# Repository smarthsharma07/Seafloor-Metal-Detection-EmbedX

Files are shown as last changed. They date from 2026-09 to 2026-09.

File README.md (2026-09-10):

# EmbedX - Seafloor Metal Detection & Target Prioritization

SIH 2026 prototype for a low-cost, deployable ocean-bottom sensor package and desktop analysis dashboard for identifying and localizing possible geophysical anomalies.

## Project Information

- **Project Title:** Low-Cost Deployable Seafloor Metal Detection Sensor for Ocean Resource Exploration
- **PS ID:** 26064
- **PS Title:** Ministry of Earth Sciences / NCPOR seafloor metal-detection and ocean resource exploration problem
- **Category:** Hardware
- **Theme:** Robotics and Drones
- **Prototype Status:** Bench bring-up and simulation verified; hardware validation remains deployment-dependent

## Problem Statement

Ocean resource exploration requires a practical way to collect and inspect multi-sensor measurements from a deployable seafloor package. A prototype must account for sensor validity, pulse-induction and magnetic responses, temperature, motion, recovery logging, and deployment drift without presenting an uncertain location as an exact target or claiming that an anomaly is a confirmed mineral deposit.

## Proposed Solution

The system combines an ESP32-based underwater sensor package with a local FastAPI desktop dashboard. The package collects pulse-induction, magnetic, temperature, inertial, and time data, stores raw telemetry locally, and exposes recovery Wi-Fi/serial access. The dashboard accepts CSV/JSON telemetry, validates and preserves the raw input, calculates conservative anomaly evidence, estimates drift uncertainty, generates IDW interpolated intensity maps, and exports results for review.

This is a decision-support prototype. It does not confirm ore, confirm a mineral, or replace geological and geophysical validation.

## Key Features

- ESP32 firmware with modular sensor drivers for MPU6050, RM3100, MAX31865/PT100, and DS3231.
- Pulse-induction waveform sampling with baseline, decay, noise, and anomaly-strength features.
- Sensor validity flags and diagnostics for each acquisition path.
- DEMO_MODE synthetic telemetry for an end-to-end demonstration without physical hardware.
- Local LittleFS CSV logging and recovery Wi-Fi/serial endpoints.
- FastAPI dashboard for CSV/JSON upload, validation, processing, mapping, and export.
- Configurable **Evidence / Confidence Score** using a rule-based heuristic. **Rule-based, not statistically calibrated.**
- Conservative result labels: `POSSIBLE_METALLIC_ANOMALY`, `POSSIBLE_THERMAL_ANOMALY`, `POSSIBLE_HYDROTHERMAL_ASSOCIATED_ANOMALY`, `MULTISENSOR_ANOMALY`, and `INSUFFICIENT_DATA`.
- IDW interpolation for the prototype heatmap, labelled **Interpolated anomaly intensity** and never treated as a direct measurement.
- Distinct map layers for deployment points, measured anomaly points, interpolated heatmap, drift uncertainty sectors, and candidate overlap regions.
- Candidate scoring based on station evidence scores, spatial overlap, and data quality. No probability-combination formula is used.
- Explicit provenance metadata on results: `MEASURED`, `CALCULATED`, `INFERRED`, or `DEMO`.
- GeoJSON and raw/processed export bundles for reproducible review.

## Scientific and Reporting Guardrails

- The evidence score is a configurable heuristic, not a calibrated probability or statistical certainty.
- The 400 m value is a deployment drift scale / uncertainty extent, not an exact target position.
- Interpolated heatmap cells are calculated estimates between measured points, not direct measurements.
- Raw telemetry is retained separately and is never overwritten by processed data.
- The system reports possible anomalies only. It never outputs `confirmed ore` or `confirmed mineral`.
- Synthetic demonstration records are explicitly tagged `DEMO`.

## Technology Stack

### Embedded package

- PlatformIO
- C++ with the Arduino ESP32 framework
- ESP32 WROOM-32E / ESP32-compatible development board
- I2C, SPI, ADC, GPIO, LittleFS, serial CLI, and recovery Wi-Fi

### Desktop software

- Python 3.10+
- FastAPI and Uvicorn
- HTML, CSS, and vanilla JavaScript frontend
- NumPy, pandas, SciPy, Shapely, and PyProj
- GeoJSON export for GIS-compatible review

## Architecture

```text
                         Surface operator
                                |
                                v
                    FastAPI desktop dashboard
              upload -> validate -> process -> export
                                |
       +------------------------+------------------------+
       |                         |                        |
       v                         v                        v
  Raw telemetry          Heuristic evidence         Map/layer outputs
  preserved              and candidate score       IDW + drift sectors
       ^                         ^                        ^
       |                         |                        |
  ESP32 recovery Wi-Fi    Sensor validity         GeoJSON/report bundle
       ^
       |
  Seafloor sensor package
  PI coil | RM3100 | PT100 | MPU6050 | DS3231
```

Detailed firmware architecture is documented in [docs/ARCHITECTURE.md](docs/ARCHITECTURE.md). The desktop implementation is organized under `desktop_software/backend/` by ingestion, preprocessing, feature extraction, detection, classification, localization, mapping, and reporting responsibilities.

## Repository Structure

```text
Seafloor-Metal-Detection-EmbedX/
├── README.md
├── platformio.ini
├── src/                              # ESP32 firmware
│   ├── main.cpp
│   ├── config.h
│   ├── sensors/                      # MPU6050, RM3100, PT100, DS3231
│   ├── pi/                           # Pulse-induction detector
│   ├── fusion/                       # Attitude, heading, drift fusion
│   ├── logging/                      # Local telemetry logging
│   ├── communication/                # Recovery Wi-Fi and HTTP endpoints
│   └── diagnostics/                  # Hardware self-tests
├── desktop_software/                 # FastAPI analysis dashboard
│   ├── main.py
│   ├── run_dashboard.bat
│   ├── backend/
│   │   ├── ingestion/ preprocessing/ features/
│   │   ├── detection/ classification/ localization/
│   │   ├── mapping/ reports/ models/ demo/
│   ├── frontend/                     # Dashboard HTML, CSS, JavaScript
│   └── data/                         # uploads, demo data, exports
├── docs/                             # Engineering and verification documents
├── test/                             # Firmware-oriented mathematical tests
├── assets/
│   ├── screenshots/                  # Dashboard and prototype images
│   ├── circuit_schematics/           # Wiring diagrams and circuit files
│   └── vessel_schematics_cad/        # Vessel/platform CAD and schematics
└── submission/                       # Presentation and demo links
```

## Installation

Clone the repository and install the desktop dependencies:

```powershell
git clone <YOUR_REPOSITORY_URL>
cd MoES_Sensor_Project_Proposal_V2
python -m venv .venv
.\.venv\Scripts\Activate.ps1
python -m pip install -r desktop_software\requirements.txt
```

PlatformIO can build the firmware from the repository root after installing PlatformIO Core or the PlatformIO IDE extension.

## Run the Desktop Prototype

From the repository root on Windows:

```powershell
desktop_software\run_dashboard.bat
```

Then open [http://127.0.0.1:8000/](http://127.0.0.1:8000/) in a browser. The dashboard must be served through this URL; opening `dashboard.html` directly from the filesystem will not load the dashboard JavaScript correctly.

For a direct Python launch:

```powershell
cd desktop_software
$env:PYTHONPATH = (Get-Location).Path
python -m uvicorn main:app --host 127.0.0.1 --port 8000
```

## Firmware Build and Test

```bash
pio run
python test/test_fusion_math.py
python test/test_prototype_corrections.py
```

The firmware must be bench-tested with the actual sensor wiring before field deployment. Hardware assumptions and unresolved items are recorded in [docs/ASSUMPTIONS.md](docs/ASSUMPTIONS.md) and [docs/KNOWN_LIMITATIONS.md](docs/KNOWN_LIMITATIONS.md).

## Future Scope

- Validate the package with controlled tank, coastal, and vessel trials.
- Replace provisional sensor parameters with calibrated field measurements.
- Add authenticated and encrypted recovery communications for operational deployments.
- Add GIS project packaging and richer survey-line planning after the prototype workflow is stable.

## Our Team

| Member | Role & Contribution |
|---|---|
| **Satwik Pavan** | **Team Leader & Circuit Design** : Led the team and designed, built, and prototyped the sensor circuit and hardware integration. |
| **Shahzeb Shahzad** | **CAD & Mechanical Design** : Led the Designing of CAD models and schematics for the payload carrier/lander and sensor payload. |
| **Smarth Sharma** | **Firmware & Software** : Led the firmware and software development, including MCU programming, sensor interfacing, and data-processing components. |
| **Piyush Goyal** | **Pulse Induction Research** : Researched pulse-induction sensing and contributed to PI coil development. |
| **Ayaan Chauhan** | **PI Coil & MCU Programming** : Worked on pulse-induction coil design and MCU programming. |
| **Shreya Jha** | **Ore Research & Presentation** : Researched relevant seafloor ore properties and developed the project presentation. |

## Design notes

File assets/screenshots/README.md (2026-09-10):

# EmbedX Software Screenshots

Screenshots demonstrating the current software prototype.

- `analysis-dashboard-synthetic.png` : Synthetic-data analysis dashboard.
- `gis-anomaly-map.png` : Geographic anomaly and drift visualization.
- `detection-thresholds.png` : Configurable anomaly detection thresholds.

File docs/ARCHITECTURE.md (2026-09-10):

# Complete Software & Firmware Architecture

This document presents the detailed architectural design of the ESP32 deployment firmware.

---

## 1. Modular Layer Diagram

```
+-------------------------------------------------------------------+
|                        APPLICATION LAYER                          |
|   src/main.cpp (State Machine Orchestrator & Serial CLI Console) |
+-------------------------------+-----------------------------------+
                                |
        +-----------------------+-----------------------+
        |                                               |
+-------v-----------------------+       +---------------+-------+
|    COMMUNICATION & LOGGING    |       |    SIGNAL PROCESSING  |
|  - WiFi Manager (HTTP Server) |       |  - Sensor Fusion      |
|  - Storage Logger (LittleFS)  |       |  - Attitude & Heading |
|  - Diagnostics Self-Test      |       |  - PI Signal Engine   |
+-------+-----------------------+       +---------------+-------+
        |                                               |
        +-----------------------+-----------------------+
                                |
+-------------------------------+-----------------------------------+
|                        HARDWARE DRIVERS                           |
|  - MPU6050 Driver (I2C)     - DS3231 Driver (I2C)                 |
|  - RM3100 Driver (SPI)      - MAX31865 Driver (SPI)               |
+-------------------------------+-----------------------------------+
                                |
+-------------------------------+-----------------------------------+
|                  HARDWARE ABSTRACTION LAYER (HAL)                 |
|  - ESP32 Wire (I2C)         - ESP32 SPI (SPISettings per dev)    |
|  - ESP32 ADC1 (GPIO32)      - ESP32 GPIO (GPIO33 Gate Pulse)      |
+-------------------------------------------------------------------+
```

---

## 2. Directory Structure

- `platformio.ini` : Project build configuration file.
- `src/config.h` : Central configuration macros, GPIO pin mappings, and parameter constants.
- `src/sensors/` : Sensor drivers (MPU6050, DS3231, MAX31865, RM3100).
- `src/pi/` : Pulse Induction coil controller and anomaly detector.
- `src/fusion/` : Attitude complementary filter, tilt-compensated heading, drift sector estimator.
- `src/logging/` : Data logger supporting CSV and LittleFS storage.
- `src/communication/` : Post-recovery Wi-Fi Access Point and HTTP server.
- `src/diagnostics/` : System self-test table and hardware health diagnostics.
- `src/main.cpp` : Entry point, non-blocking time-multiplexed loop state machine, CLI command parser.

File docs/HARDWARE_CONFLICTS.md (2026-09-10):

# Hardware Conflicts & Discrepancies Resolution Report

This document records all conflicts, discrepancies, and contradictions identified across project documents and hardware schematics, along with their engineering resolutions.

---

## 1. Discrepancy Matrix

| Discrepancy ID | Item | Source Document A | Source Document B | Engineering Resolution | Status |
| :--- | :--- | :--- | :--- | :--- | :--- |
| **CONFLICT-01** | Magnetometer Part | PDF 1 & PDF 2 (MMC5983MA / QMC5883L) | PDF 3 & Prompt (RM3100) | Standardized on **RM3100** via SPI bus. QMC5883L/MMC5983MA code excluded. | **RESOLVED** |
| **CONFLICT-02** | I2C Address Collision | MPU6050 schematic (R6=4.7k to GND -> `0x68`) | DS3231 RTC datasheet (Fixed `0x68`) | MPU6050 `AD0` pin **must** be tied to 3.3V (`0x69`). Dynamic probe implemented. | **RESOLVED IN FIRMWARE** |
| **CONFLICT-03** | I2C SCL Pin Mapping | Project prompt text (`I2C SCL -> GPIO?`) | Olimex ESP32-POE EXT2 header (Pin 4 = `GPIO16`) | Set default `I2C_SCL_PIN` to `GPIO16` in `config.h`. Configurable via macro. | **HARDWARE_TBD** |
| **CONFLICT-04** | SPI Clock Mode Conflict | MAX31865 datasheet (Mode 1 / Mode 3, CPHA=1) | RM3100 datasheet (Mode 0, CPOL=0, CPHA=0) | Implemented per-device `SPISettings` before asserting Chip Select. | **RESOLVED IN FIRMWARE** |
| **CONFLICT-05** | MAX31865 $R_{ref}$ Value | Generic MAX31865 docs ($400.0\,\Omega$) | 7Semi Breakout PCB image (Page 1) | Set provisional default $R_{ref} = 430.0\,\Omega$. Marked `UNVERIFIED`. | **HARDWARE_TBD** |

---

## 2. Detailed Technical Evidence & Direct Quotes

### Conflict 01: Magnetometer Sensor Type
- **PDF 1 (Vessel Movement-Direction Prediction, Page 1):**
  > "Three Sources of Direction Information: MMC5983MA magnetometer - Measures the Earth's magnetic-field vector..."
- **PDF 2 (Project Proposal & Concept Note, Page 4):**
  > "Magnetometer: QMC5883L (Unconfirmed)"
- **PDF 3 (Sensor Schematics, Page 3):**
  > "Magnetometer – RM3100: SPI interface (SCK, SO, SI, SSN, DRDY, I2CEN=GND)"
- **User Request Instructions:**
  > "The latest hardware design uses RM3100. Do NOT implement QMC5883L support unless explicitly requested later."
- **Resolution:** `RM3100` driver implemented via SPI.

### Conflict 02: I2C Address Collision between MPU6050 and DS3231
- **PDF 3 (MPU6050 Schematic, Page 2):**
  > Circuit schematic shows resistor `R6 (4.7K)` pulling `AD0` pin to `GND`. When `AD0` is LOW, MPU6050 I2C 7-bit slave address is `0x68`.
- **DS3231 Datasheet Standard:**
  > Fixed 7-bit slave address `0x68`.
- **Engineering Risk:** If both chips share address `0x68` on the same I2C bus, bus contention occurs and both devices fail to read.
- **Resolution:**
  1. Hardware requirement: Tie MPU6050 `AD0` externally to `3.3V` (sets address to `0x69`).
  2. Software safety: `MPU6050` driver tests `0x69` first; if not detected, attempts `0x68` only if DS3231 probe is inactive.

### Conflict 03: I2C SCL Pin Mapping
- **User Prompt:**
  > `I2C: SDA -> GPIO13, SCL -> GPIO?`
- **Olimex ESP32-POE EXT2 Header Analysis:**
  > EXT2 Pin 3 = `GPIO13` (SDA)
  > EXT2 Pin 4 = `GPIO16` (SCL)
- **Resolution:** Set default `I2C_SCL_PIN` to `16` in `src/config.h`, but explicitly document as `HARDWARE_TBD` until physical bench continuity check is confirmed.

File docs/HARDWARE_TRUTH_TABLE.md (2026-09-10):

# Hardware Truth Table & Pre-Flight Review

This document establishes the hardware verification matrix for the deployable ocean-bottom sensor package based on direct inspection of supplied schematics, breakout board pinouts, and project architecture documents.

> [!CAUTION]
> **PRE-FLIGHT HARDWARE STATUS:** All GPIO assignments are currently classified as **PROVISIONAL / BENCH_TBD** pending physical electrical continuity checks and confirmation of the exact PCB revision.

---

## 1. Peripheral Hardware Matrix

| Function | Device | ESP32 GPIO | Physical Header Pin | Bus | Direction | Active Level | Voltage | Source Document | Verification Status | Engineering Notes |
| :--- | :--- | :--- | :--- | :--- | :--- | :--- | :--- | :--- | :--- | :--- |
| **I2C SDA** | MPU6050 / DS3231 | `GPIO13` | EXT2 Pin 3 | I2C | Bidirectional | Open-Drain (4.7k Pull-up) | 3.3V | Project Wiring / EXT2 Map | **PROVISIONAL (BENCH_TBD)** | Shared I2C Data line. |
| **I2C SCL** | MPU6050 / DS3231 | `GPIO16` *(Default)* | EXT2 Pin 4 | I2C | Output | Open-Drain (4.7k Pull-up) | 3.3V | Olimex EXT2 Reference / Prompt `GPIO?` | **UNVERIFIED (BENCH_TBD)** | Prompt states `GPIO?`. EXT2 Pin 4 is GPIO16 on Olimex WROOM. |
| **SPI MISO** | RM3100 / MAX31865 | `GPIO2` | EXT1 Pin 3 | SPI | Input | Logic | 3.3V | Project Wiring / EXT1 Map | **PROVISIONAL (BENCH_TBD)** | Shared Master-In-Slave-Out line. |
| **SPI MOSI** | RM3100 / MAX31865 | `GPIO15` | EXT2 Pin 8 | SPI | Output | Logic | 3.3V | Project Wiring / EXT2 Map | **PROVISIONAL (BENCH_TBD)** | Shared Master-Out-Slave-In line. |
| **SPI SCK** | RM3100 / MAX31865 | `GPIO14` | EXT2 Pin 7 | SPI | Output | Logic | 3.3V | Project Wiring / EXT2 Map | **PROVISIONAL (BENCH_TBD)** | Shared Serial Clock line. |
| **RM3100 CS** | RM3100 Magnetometer | `GPIO4` | EXT1 Pin 4 | SPI CS | Output | Active LOW | 3.3V | Project Wiring / EXT1 Map | **PROVISIONAL (BENCH_TBD)** | Dedicated SPI Chip Select (SSN). SPI Mode 0. |
| **MAX31865 CS** | MAX31865 RTD | `GPIO5` | EXT1 Pin 5 | SPI CS | Output | Active LOW | 3.3V | Project Wiring / EXT1 Map | **PROVISIONAL (BENCH_TBD)** | Dedicated SPI Chip Select. SPI Mode 1. |
| **PI Trigger** | PI MOSFET Gate | `GPIO33` | EXT2 Pin 5 | GPIO | Output | Active HIGH | 3.3V -> Gate | Project Wiring / EXT2 Map | **PROVISIONAL (BENCH_TBD)** | Pulse Induction MOSFET gate pulse. |
| **PI ADC Input** | PI Decay Signal | `GPIO32` | EXT2 Pin 6 | ADC1_CH4 | Analog Input | Analog (0-3.3V) | 0-3.3V | Project Wiring / EXT2 Map | **PROVISIONAL (BENCH_TBD)** | ADC1 Channel 4; unaffected by Wi-Fi operations. |
| **DS3231 Address** | DS3231 RTC | N/A (I2C: `0x68`) | N/A | I2C | N/A | N/A | 3.3V | DS3231 Datasheet | **VERIFIED (I2C Standard)** | Fixed I2C slave address `0x68`. Initialized first in setup. |
| **MPU6050 Address** | MPU6050 IMU | N/A (I2C: `0x69`) | N/A | I2C | N/A | N/A | 3.3V | MPU6050 Schematic (Page 2) | **MANDATORY HARDWARE REQUIREMENT** | Breakout schematic shows R6 4.7k pull-down on AD0 (`0x68`). Must wire AD0 to 3.3V (`0x69`) to avoid bus collision. |
| **RM3100 I2CEN** | RM3100 Magnetometer | N/A (GND) | N/A | Discrete | Input | Active LOW (GND) | 0V | Sensor Schematics (Page 3) | **PROVISIONAL (BENCH_TBD)** | Must be tied to GND to force SPI protocol mode. |
| **MAX31865 $R_{ref}$**| 7Semi Board Resistor | N/A | PCB Surface | Analog | Precision | N/A | N/A | 7Semi Breakout PCB (Page 1) | **UNVERIFIED (BENCH_TBD)** | Default $430.0\,\Omega$. Must measure SMD resistor on physical board. |

---

## 2. Power and Grounding Architecture

- **Main Input:** $5.0\,\text{V}$ DC from step-down buck converter powered by $12\,\text{V}, 5\,\text{Ah}$ Li-Ion battery pack.
- **Sensor Logic Power:** $3.3\,\text{V}$ rail for MPU6050, DS3231, RM3100 (AVDD/DVDD), and MAX31865 (VIN/3V3).
- **Grounding Requirement:** Star-ground topology connecting digital logic ground, analog sensor ground, and MOSFET source return at a single point to prevent high-current PI induction switching transients from corrupting RTD and magnetometer readings.

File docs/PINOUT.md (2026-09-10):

# Hardware Pinout & Wiring Specification

This document provides the verified pinout and physical header wiring mapping for the ESP32 deployment package.

---

## 1. ESP32 Extension Header Pin Assignments

```
               Olimex ESP32-POE / WROOM Extension Headers

         EXT1 (Left Header)                EXT2 (Right Header)
      +----------------------+          +----------------------+
      | 1 : 3.3V Power       |          | 1 : 5.0V Power       |
      | 2 : GND              |          | 2 : GND              |
      | 3 : GPIO2  (MISO)    |          | 3 : GPIO13 (I2C SDA) |
      | 4 : GPIO4  (RM CS)   |          | 4 : GPIO16 (I2C SCL)*|
      | 5 : GPIO5  (MAX CS)  |          | 5 : GPIO33 (PI Gate) |
      | 6 : GPIO18           |          | 6 : GPIO32 (PI ADC)  |
      | ...                  |          | 7 : GPIO14 (SPI SCK) |
      +----------------------+          | 8 : GPIO15 (SPI MOSI)|
                                        +----------------------+
```

*Note: SCL is mapped to EXT2 Pin 4 (`GPIO16`). Default configurable via `I2C_SCL_PIN` in `config.h`.

---

## 2. Bus Allocation Summary

### I2C Bus (`Wire`)
- **SDA:** `GPIO13` (EXT2 Pin 3)
- **SCL:** `GPIO16` (EXT2 Pin 4) - *HARDWARE_TBD*
- **Devices:**
  - `DS3231` RTC (Fixed address `0x68`)
  - `MPU6050` IMU (Address `0x69` when AD0 tied to 3.3V)

### SPI Bus (`SPI`)
- **MOSI:** `GPIO15` (EXT2 Pin 8)
- **MISO:** `GPIO2`  (EXT1 Pin 3)
- **SCK:**  `GPIO14` (EXT2 Pin 7)
- **Devices:**
  - `RM3100` Magnetometer (`CS` = `GPIO4`, SPI Mode 0, 1 MHz max)
  - `MAX31865` RTD Converter (`CS` = `GPIO5`, SPI Mode 1/3, 1 MHz max)

### Discrete Analog / GPIO
- **PI MOSFET Gate Trigger:** `GPIO33` (EXT2 Pin 5) - Digital Output
- **PI Signal Decay ADC Input:** `GPIO32` (EXT2 Pin 6) - `ADC1_CH4`

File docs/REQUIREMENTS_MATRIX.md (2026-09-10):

# Requirements Traceability Matrix

This document maps all SIH project requirements to firmware implementation modules, input/output interfaces, and verification statuses.

---

## 1. Traceability Matrix

| Req ID | Requirement Description | Implementation Module | Primary Input | Primary Output | Verification Method | Status |
| :--- | :--- | :--- | :--- | :--- | :--- | :--- |
| **REQ-DRV-01** | MPU6050 Motion Sensing & Die Temp | `src/sensors/mpu6050.h/cpp` | I2C Bus (`0x69` default) | Accel ($\text{m}/\text{s}^2$), Gyro ($\text{rad}/\text{s}$), Die Temp ($^\circ\text{C}$), `mpu_valid` | Startup Identity Check (`WHO_AM_I=0x68`), Static Code Review | **[SOURCE VERIFIED]** (Pending Bench Test) |
| **REQ-DRV-02** | DS3231 RTC Timestamping | `src/sensors/ds3231.h/cpp` | I2C Bus (`0x68` fixed) | Unix Epoch, ISO-8601 String, `rtc_valid` | Range Sanity Check & Status Probe | **[SOURCE VERIFIED]** (Pending Bench Test) |
| **REQ-DRV-03** | MAX31865 Seawater Temperature | `src/sensors/max31865_pt100.h/cpp` | SPI Bus (`GPIO5` CS, Mode 1) | RTD Ohms, Seawater Temp ($^\circ\text{C}$), `rtd_valid` | Quadratic CVD Math & Config Readback | **[SOURCE VERIFIED]** (Pending Bench Test) |
| **REQ-DRV-04** | RM3100 3-Axis Magnetometer | `src/sensors/rm3100.h/cpp` | SPI Bus (`GPIO4` CS, Mode 0) | Magnetic Vector ($\mu\text{T}$), `mag_valid` | REVID Check (`0x36`) & CC Readback | **[SOURCE VERIFIED]** (Pending Bench Test) |
| **REQ-PI-01** | Parameterized PI Anomaly Detector | `src/pi/pi_detector.h/cpp` | `GPIO33` Gate, `GPIO32` ADC1_CH4 | Raw Decay[16], Baseline, Peak, Early/Late, Strength, `pi_valid` | Multi-burst Acquisition & Sigma Derivation | **[PROVISIONAL]** (Pending Coil Bench Test) |
| **REQ-FUS-01** | IMU Attitude Filter (Roll/Pitch) | `src/fusion/attitude.h/cpp` | Calibrated Accel & Gyro | Roll ($\phi$), Pitch ($\theta$) | Mathematical Simulation | **[SOURCE VERIFIED]** |
| **REQ-FUS-02** | Tilt-Compensated Heading | `src/fusion/heading.h/cpp` | Calibrated Mag + Roll/Pitch | Heading ($\psi$, $0-360^\circ$), Calibrated $\mu\text{T}$ | Synthetic Vector Test (`test_fusion_math.py`) | **[SIMULATION VERIFIED]** |
| **REQ-FUS-03** | Conditional Drift Sector Fusion | `src/fusion/drift_fusion.h/cpp` | Mag Heading + IMU Motion | `accel_horiz_mag`, `imu_direction_valid`, `drift_bearing`, `drift_radius`, `uncertainty_deg` | Synthetic Vector Test (`test_fusion_math.py`) | **[SIMULATION VERIFIED]** |
| **REQ-FUS-04** | Separate Confidence Metrics | `src/fusion/drift_fusion.h/cpp` | Field Magnitude & Motion SNR | `mag_conf`, `imu_conf`, `fusion_conf` | Confidence Metric Analysis | **[SIMULATION VERIFIED]** |
| **REQ-LOG-01** | Telemetry Data Logging | `src/logging/logger.h/cpp` | Unified `SensorSample` | LittleFS CSV File (`/telemetry.csv`) | Storage Schema Review | **[SOURCE VERIFIED]** |
| **REQ-COM-01** | Recovery Wi-Fi Server | `src/communication/wifi_manager.h/cpp` | LittleFS Files | Endpoints: `/`, `/status`, `/config`, `/calibration`, `/files`, `/download` | HTTP Route Handler Review | **[SOURCE VERIFIED]** |
| **REQ-SIM-01** | DEMO_MODE Simulation Engine | `src/main.cpp` | Synthetic Timers | Full Simulated Telemetry Pipeline | End-to-End Simulation Step | **[SOURCE VERIFIED]** |
| **REQ-DIAG-01**| Boot Diagnostics & CLI | `src/diagnostics/diagnostics.h/cpp` & `src/main.cpp` | Sensor Init Status & CLI | Self-Test Table, CLI (`piread`, `pical`, `magcal`, `imucal`, `demo`) | Interactive CLI Review | **[SOURCE VERIFIED]** |

---

## 2. Verification Classification Standard

1. **`[SOURCE VERIFIED]`**: Code structure, driver registers, error handling, and syntax verified via code review and static analysis.
2. **`[SIMULATION VERIFIED]`**: Mathematical algorithms (attitude filter, heading projection, conditional IMU motion, drift fusion) validated against synthetic test vectors (`test/test_fusion_math.py`).
3. **`[PROVISIONAL / BENCH_TBD]`**: Hardware interactions (PI coil decay curves, RTD reference resistor, SCL pin continuity) requiring physical bench testing.
4. **`[BENCH HARDWARE VERIFIED]`**: Validated on physical electronics workbench with actual breakout boards. *(PENDING).*
5. **`[FIELD VERIFIED]`**: Confirmed during open-ocean sea trials and drift deployment experiments. *(PENDING).*

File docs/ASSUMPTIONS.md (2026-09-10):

# Engineering Assumptions Document

This document lists every explicit engineering assumption made during the design and software architecture of the deployable seafloor metal-detection sensor package.

---

## 1. Hardware & Electrical Assumptions

1. **ESP32 Board Mapping:** Assumed Olimex ESP32-POE or compatible ESP32-WROOM-32E module pinout. `I2C_SCL_PIN` defaults to `GPIO16` (EXT2 Pin 4) as a provisional value, marked `UNVERIFIED BENCH_TBD`.
2. **I2C Pull-Up Resistors:** Assumed physical pull-up resistors ($4.7\,\text{k}\Omega$) are present on `SDA` (`GPIO13`) and `SCL` (`GPIO16`).
3. **MPU6050 Address Modification:** Mandatory requirement that MPU6050 `AD0` pin is tied to `3.3V` to force address `0x69`, avoiding hard bus collision with the DS3231 RTC (`0x68`).
4. **MAX31865 Reference Resistor:** Assumed 7Semi MAX31865 module uses a $430.0\,\Omega$ reference resistor ($R_{ref} = 430.0\,\Omega$) for PT100 elements. Marked `UNVERIFIED BENCH_TBD`.
5. **PT100 Configuration:** Assumed 2-wire PT100 RTD with Callendar-Van Dusen equation coefficients ($R_0 = 100.0\,\Omega, A = 3.9083 \times 10^{-3}, B = -5.775 \times 10^{-7}$).
6. **PI Coil Hardware Isolation:** Assumed the Pulse Induction MOSFET driver circuit includes flyback clamping diodes and voltage divider networks to clamp decay signals within the ESP32 `ADC1` range ($0.0\,\text{V} - 3.3\,\text{V}$).

---

## 2. Localization & Sensor Fusion Assumptions

7. **Passive Hydrodynamic Fin Alignment:** Assumed mechanical current-alignment fins passively rotate the cylindrical housing so its longitudinal axis aligns with the local current vector.
8. **No Electronic Fin Sensor:** Assumed there is **no electronic sensor** monitoring fin angle relative to the vessel. The magnetometer reading represents the current-aligned direction directly.
9. **Short-Term IMU Role:** Assumed MPU6050 accelerometer and gyroscope data are used exclusively for tilt compensation and short-term transient motion estimation, **not for long-duration 400 m underwater dead-reckoning**.
10. **Default Drift Scale:** Assumed nominal deployment-to-seafloor drift distance is $400\,\text{m}$ (configurable parameter).

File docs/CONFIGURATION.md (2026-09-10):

# Configuration & Parameters Guide

This document describes all centralized configuration macros, parameter structures, default values, and runtime modification interfaces.

---

## 1. Global Configuration Structure (`src/config.h`)

### Hardware Pin Definitions
```cpp
#define I2C_SDA_PIN         13      // EXT2 Pin 3
#define I2C_SCL_PIN         16      // EXT2 Pin 4 (HARDWARE_TBD)
#define SPI_MOSI_PIN        15      // EXT2 Pin 8
#define SPI_MISO_PIN        2       // EXT1 Pin 3
#define SPI_SCK_PIN         14      // EXT2 Pin 7
#define RM3100_CS_PIN       4       // EXT1 Pin 4
#define MAX31865_CS_PIN     5       // EXT1 Pin 5
#define PI_MOSFET_GATE_PIN  33      // EXT2 Pin 5
#define PI_ADC_INPUT_PIN    32      // EXT2 Pin 6 (ADC1_CH4)
```

### Sensor Settings & Bus Speeds
```cpp
#define I2C_BUS_SPEED       400000U // 400 kHz Fast-mode I2C
#define MPU6050_I2C_ADDR    0x69    // Address with AD0 pulled HIGH
#define DS3231_I2C_ADDR     0x68    // Fixed RTC Address
#define MAX31865_RREF       430.0f  // Reference resistor (UNVERIFIED)
#define MAX31865_RNOMINAL   100.0f  // PT100 Nominal 0C resistance
```

### Pulse Induction Engine Parameters
```cpp
#define PI_PULSE_WIDTH_US   150     // PROVISIONAL
#define PI_SETTLING_DELAY_US 30     // PROVISIONAL
#define PI_PULSE_PERIOD_US  1000    // PROVISIONAL
#define PI_SAMPLE_COUNT     16      // Decay curve samples
#define PI_AVERAGING_COUNT  20      // Pulse averaging
```

---

## 2. Runtime CLI Configuration

All parameters can be queried and modified at runtime via the serial console interface using commands:
- `config` : Prints current parameter list.
- `set pitime <width_us> <settle_us> <period_us>` : Updates PI timing parameters.
- `set dithresh <threshold_counts>` : Updates PI metal anomaly detection threshold.
- `set drift <radius_m> <angle_deg>` : Updates drift radius and sector uncertainty angle.

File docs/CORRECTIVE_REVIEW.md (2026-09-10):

# Engineering Corrective Review & Gap Analysis

This document records the systematic review of the SIH seafloor metal-detection sensor package codebase and documentation, identifying discrepancies, severity levels, root causes, proposed fixes, and hardware verification requirements.

---

## 1. Discrepancy & Defect Register

| ID | Category | Issue Description | Severity | Evidence in Code / Docs | Proposed Engineering Fix | Hardware Verification Required? |
| :--- | :--- | :--- | :--- | :--- | :--- | :--- |
| **CR-01** | Hardware / Pinout | Premature declaration of GPIO pinout as confirmed without physical continuity test. | **HIGH** | `HARDWARE_TRUTH_TABLE.md` listed pins as CONFIRMED based on Olimex reference diagrams. | Reclassify all pins as `PROVISIONAL / BENCH_TBD` until physical continuity and board revision are confirmed. | **YES** |
| **CR-02** | I2C Protocol / Safety | MPU6050 fallback probe to `0x68` creates unsafe bus collision with DS3231 RTC. | **CRITICAL** | `mpu6050.cpp` probed `0x68` if `0x69` failed, potentially driving DS3231. | Initialize DS3231 at `0x68` first. Strictly enforce MPU6050 at `0x69`. Abort with clear error if `0x69` is missing. | **YES** |
| **CR-03** | Data Model | Temperature collision: MPU6050 internal die temperature overwrote PT100 seawater temperature. | **CRITICAL** | `main.cpp` passed `g_latestSample.temperature_C` to `g_mpu.readScaled()`, overwriting PT100 reading. | Separate into `water_temperature_C` (MAX31865 PT100) and `imu_temperature_C` (MPU6050 die temp) in `SensorSample`. | **NO** (Software fix) |
| **CR-04** | Serial CLI | `piread` command only printed stale cached telemetry rather than triggering an active measurement. | **MEDIUM** | `main.cpp` printed `g_latestSample.pi_response_strength` without invoking `g_pi.processPulseSequence()`. | Execute a live PI pulse sequence within `piread` CLI handler and print real-time decay and delta counts. | **YES** (Bench verification) |
| **CR-05** | Calibration CLI | `magcal`, `imucal`, and `pical` routines were documented but lacked implementation in CLI. | **HIGH** | `main.cpp` lacked logic for multi-point mag sampling and stationary gyro offset averaging. | Implement multi-sample interactive calibration loops in `main.cpp` and update `HeadingCalculator` / `AttitudeFilter`. | **YES** (Bench verification) |
| **CR-06** | Web Recovery API | Endpoints `/config` and `/calibration` were documented in help/docs but not bound in `wifi_manager.cpp`. | **MEDIUM** | `wifi_manager.cpp` only had `/`, `/status`, `/files`, `/download`. | Implement dedicated `/config` (JSON) and `/calibration` (JSON) endpoints in `WiFiRecoveryManager`. | **NO** (Software fix) |
| **CR-07** | Logging Claims | Documentation claimed "binary log format" support when only CSV logging is implemented. | **LOW** | `DATA_FORMAT.md` & `ARCHITECTURE.md` mentioned binary format. | Remove all binary logging claims. Explicitly document LittleFS CSV logging as the sole storage format. | **NO** (Doc fix) |
| **CR-08** | RTD Math | Linear Callendar-Van Dusen equation used ($R(T) = R_0(1+AT)$), omitting second-order $B T^2$ term. | **MEDIUM** | `max31865_pt100.cpp` used linear equation while docs claimed full CVD. | Implement quadratic Callendar-Van Dusen formula for $T \ge 0^\circ\text{C}$ and accurately document the calculation. | **NO** (Math fix) |
| **CR-09** | RTD Hardware | $R_{ref} = 430.0\,\Omega$ was hardcoded without measuring the physical 7Semi board resistor. | **HIGH** | `config.h` defined `MAX31865_RREF_OHMS 430.0f`. | Maintain configurable $R_{ref}$ and explicitly mark as `UNVERIFIED / BENCH_TBD`. | **YES** |
| **CR-10** | PI Concurrency | PI pulse sequence claimed to be non-blocking but utilized microsecond delay loops. | **HIGH** | `pi_detector.cpp` used synchronous `delayMicroseconds()` loops. | Clarify that PI pulse bursts require microsecond-level timing and implement non-blocking inter-pulse state scheduling. | **YES** |
| **CR-11** | RM3100 Gain | Fixed 75 LSB/uT gain assumed cycle count of 200 without runtime verification. | **MEDIUM** | `rm3100.cpp` assumed default 200 counts without verifying register write success. | Verify cycle count register readback during `begin()` before applying 75 LSB/uT gain factor. | **YES** |
| **CR-12** | Drift Fusion Claims | Documentation risked implying 400 m dead reckoning. | **HIGH** | Various docs needed clearer distinction between drift sector estimation and dead reckoning. | Emphasize throughout all docs that drift fusion is a statistical uncertainty sector model, NOT dead reckoning. | **NO** (Doc fix) |
| **CR-13** | Traceability | `REQUIREMENTS_MATRIX.md` claimed `[BUILD VERIFIED]` before environment build execution. | **MEDIUM** | Requirements matrix marked statuses optimistically. | Re-evaluate verification statuses honestly against strict build and simulation criteria. | **NO** (Doc fix) |

---

## 2. Corrective Action Plan

1. **Step 1:** Update `src/config.h` with separated temperature fields, unverified markers, and clean calibration structs.
2. **Step 2:** Refactor `src/sensors/mpu6050.cpp` to eliminate `0x68` fallback when DS3231 is active.
3. **Step 3:** Implement quadratic Callendar-Van Dusen equation and register readback verification in `src/sensors/max31865_pt100.cpp`.
4. **Step 4:** Implement cycle count verification in `src/sensors/rm3100.cpp`.
5. **Step 5:** Refactor `src/pi/pi_detector.cpp` with honest timing documentation and non-blocking pulse acquisition cycle.
6. **Step 6:** Implement full interactive `magcal`, `imucal`, and `pical` routines and live `piread` in `src/main.cpp`.
7. **Step 7:** Implement `/config` and `/calibration` endpoints in `src/communication/wifi_manager.cpp`.
8. **Step 8:** Reconcile all 15 documentation files to remove unimplemented features (e.g. binary logging) and accurately describe approximations, calibration workflows, and provisional parameters.

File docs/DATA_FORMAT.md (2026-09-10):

# Data Format Specification

This document details the telemetry logging CSV file format and the JSON schemas served by the Wi-Fi Recovery web server.

---

## 1. Local LittleFS CSV Telemetry Log (`/telemetry.csv`)

Telemetry is written directly to the onboard LittleFS filesystem as a standardized CSV file.

### CSV Header Definition
```csv
timestamp,water_temp_C,imu_temp_C,rtd_ohms,accel_x,accel_y,accel_z,gyro_x,gyro_y,gyro_z,mag_x,mag_y,mag_z,heading,roll,pitch,pi_strength,pi_detected,drift_bearing,confidence
```

### Sample Record
```csv
2026-09-07T14:30:00.000Z,24.15,31.20,109.42,0.02,-0.01,9.81,0.001,-0.002,0.000,21.50,-12.30,42.10,145.20,0.12,-0.06,12.4,0,145.20,0.85
```

### Column Field Descriptions
| Column Index | Field Name | Unit | Type | Description |
| :--- | :--- | :--- | :--- | :--- |
| 1 | `timestamp` | ISO-8601 UTC | String | Formatted UTC timestamp retrieved from DS3231 RTC. |
| 2 | `water_temp_C` | $^\circ\text{C}$ | Float | Seawater temperature measured by MAX31865 PT100 probe. |
| 3 | `imu_temp_C` | $^\circ\text{C}$ | Float | Internal MPU6050 die temperature. |
| 4 | `rtd_ohms` | $\Omega$ | Float | Measured RTD probe resistance. |
| 5-7 | `accel_x, accel_y, accel_z` | $\text{m}/\text{s}^2$ | Float | Calibrated 3-axis acceleration. |
| 8-10 | `gyro_x, gyro_y, gyro_z` | $\text{rad}/\text{s}$ | Float | Calibrated 3-axis angular rates. |
| 11-13 | `mag_x, mag_y, mag_z` | $\mu\text{T}$ | Float | Calibrated 3-axis magnetic field vector. |
| 14 | `heading` | Degrees ($0-360^\circ$) | Float | Tilt-compensated magnetic heading. |
| 15-16 | `roll, pitch` | Degrees | Float | Computed vessel attitude from complementary filter. |
| 17 | `pi_strength` | ADC Counts | Float | Pulse Induction decay anomaly magnitude above baseline. |
| 18 | `pi_detected` | Boolean ($0/1$) | Integer | 1 if `pi_strength` exceeds threshold; 0 otherwise. |
| 19 | `drift_bearing` | Degrees ($0-360^\circ$) | Float | Estimated current-aligned dominant drift bearing. |
| 20 | `confidence` | Scale ($0.0 - 1.0$) | Float | Directional sector fusion confidence score. |

---

## 2. Recovery Wi-Fi JSON API Endpoints

### A. Live Status API (`GET /status`)
```json
{
  "timestamp": "2026-09-07T14:30:00.000Z",
  "water_temperature_C": 24.15,
  "imu_temperature_C": 31.20,
  "rtd_ohms": 109.42,
  "accel": {"x": 0.02, "y": -0.01, "z": 9.81},
  "gyro": {"x": 0.001, "y": -0.002, "z": 0.000},
  "mag_uT": {"x": 21.50, "y": -12.30, "z": 42.10},
  "heading_deg": 145.20,
  "attitude": {"roll_deg": 0.12, "pitch_deg": -0.06},
  "pi_detector": {
    "strength": 12.4,
    "detected": false,
    "baseline": 105.2
  },
  "drift_fusion": {
    "bearing_deg": 145.20,
    "uncertainty_deg": 30.0,
    "radius_m": 400.0,
    "confidence": 0.85
  }
}
```

### B. Configuration API (`GET /config`)
```json
{
  "i2c": {"sda": 13, "scl": 16, "speed": 400000, "mpu_addr": "0x69", "ds3231_addr": "0x68"},
  "spi": {"sck": 14, "miso": 2, "mosi": 15, "rm3100_cs": 4, "max31865_cs": 5},
  "pi": {"gate_gpio": 33, "adc_gpio": 32, "width_us": 150, "settle_us": 30, "period_us": 1000, "threshold": 50.0},
  "fusion": {"w_mag": 0.80, "w_imu": 0.20, "drift_radius_m": 400.0, "uncertainty_deg": 30.0}
}
```

### C. Calibration API (`GET /calibration`)
```json
{
  "mag": {
    "offset": {"x": 2.15, "y": -1.40, "z": 5.80},
    "scale": {"x": 1.02, "y": 0.98, "z": 1.00},
    "calibrated": true
  },
  "imu": {
    "accel_offset": {"x": 0.015, "y": -0.020, "z": 0.005},
    "gyro_offset": {"x": 0.0012, "y": -0.0008, "z": 0.0002},
    "calibrated": true
  }
}
```

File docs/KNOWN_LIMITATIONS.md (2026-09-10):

# Prototype Scope & Known Limitations

This document explicitly defines the engineering boundaries, prototype scope, and known physical/electrical/algorithmic limitations of the deployable seafloor metal-detection sensor package.

---

## 1. Prototype Scope

The primary objective of this SIH hardware prototype is to validate a low-cost deployable ocean-bottom sensor architecture capable of:
1. Detecting conductive seafloor metallic anomalies using a parameterized Pulse Induction (PI) coil.
2. Estimating a constrained directional drift sector ($\pm 30^\circ$ around dominant heading) from surface deployment coordinates rather than assuming an unconstrained 400 m circle.
3. Recording seawater temperature via a PT100 RTD interface and timestamping environmental data.
4. Providing local LittleFS CSV telemetry logging and post-recovery Wi-Fi data offload.

> [!IMPORTANT]
> **PROTOTYPE BOUNDARY:**
> - The prototype is designed for bench bring-up, pressure chamber testing, and near-shore prototype drift trials.
> - It is **NOT** a certified commercial deep-sea oceanographic instrument.

---

## 2. Known System Limitations

### A. Localization & Sensor Fusion Limitations
1. **No Inertial Dead Reckoning:**
   The MPU6050 6-axis MEMS IMU is used solely for tilt compensation and short-term horizontal acceleration detection. Accelerometer bias and integration drift prevent long-duration underwater dead reckoning. The system does not claim exact $(x, y)$ seabed coordinates.
2. **Passive Fin Dependency:**
   The directional drift estimate assumes the vessel's passive mechanical fins have hydrodynamically aligned with the dominant underwater current. There is no electronic fin angle sensor.
3. **Absence of Acoustic Positioning:**
   The system does not include a Doppler Velocity Log (DVL) or Ultra-Short Baseline (USBL) acoustic positioning transponder.

### B. Electrical & Hardware Limitations
4. **I2C Bus Contention:**
   The DS3231 RTC fixed address `0x68` collides with the MPU6050 default address. The MPU6050 `AD0` pin **must** be wired to $3.3\,\text{V}$ (address `0x69`).
5. **PI Coil Mutual Electromagnetic Interference:**
   High-current PI switching pulses severely distort local magnetic fields. The firmware enforces time-multiplexing to ensure the RM3100 magnetometer is never read during PI pulse firing.
6. **Internal ADC Non-Linearity:**
   The internal ESP32 12-bit ADC (`GPIO32` / `ADC1_CH4`) exhibits non-linearity near $0.0\,\text{V}$ and $3.3\,\text{V}$. Precise PI decay analysis requires baseline calibration.

### C. Operational Limitations
7. **Submerged Wi-Fi Inoperability:**
   2.4 GHz RF signals are absorbed by seawater. Wi-Fi recovery mode operates only after physical retrieval to the research vessel.
8. **Provisional Parameters:**
   PI pulse timings ($150\,\mu\text{s}$ width, $30\,\mu\text{s}$ settle) and MAX31865 $R_{ref}$ ($430\,\Omega$) are provisional defaults and must be tuned on the physical hardware.

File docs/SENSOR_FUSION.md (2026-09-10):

# Sensor Fusion & Directional Drift Estimation

This document describes the mathematical formulation of the attitude estimation, tilt-compensated heading, and current-aligned drift sector fusion algorithm.

> [!IMPORTANT]
> **CRITICAL CONCEPTUAL CLARIFICATION:**
> The fusion algorithm implements a **statistical directional uncertainty sector model**, NOT a dead-reckoning positioning system. Due to sensor noise and double integration error, MEMS accelerometers cannot estimate long-duration underwater position. The drift direction is constrained primarily by hydrodynamic fin alignment measured by the magnetometer.

---

## 1. Frame Conventions

```
              BODY FRAME CONVENTION (Cylindrical Vessel)
              
                      +X (Forward / Fin Nose)
                        ^
                        |
            +Y (Port) <--+--> -Y (Starboard)
                        |
                        v
                      +Z (Down / Bottom)
```

- **Body Frame ($B$):**
  - $+X$: Forward facing along vessel longitudinal axis.
  - $+Y$: Port (Left).
  - $+Z$: Downward along cylinder axis.
- **Global Geographic Frame ($G$):**
  - $X_G$: Magnetic North ($0^\circ$).
  - $Y_G$: Magnetic East ($90^\circ$).
  - $Z_G$: Downward toward gravity vector.

---

## 2. Mathematical Formulation

### A. IMU Attitude Complementary Filter
Pitch ($\theta$) and Roll ($\phi$) are updated by combining gyroscope integration with accelerometer gravity vector sensing:

$$\phi_{\text{accel}} = \text{atan2}(a_y, a_z)$$
$$\theta_{\text{accel}} = \text{atan2}(-a_x, \sqrt{a_y^2 + a_z^2})$$

$$\phi(k) = \alpha \cdot (\phi(k-1) + \omega_x \Delta t) + (1 - \alpha) \cdot \phi_{\text{accel}}$$
$$\theta(k) = \alpha \cdot (\theta(k-1) + \omega_y \Delta t) + (1 - \alpha) \cdot \theta_{\text{accel}}$$

where $\alpha = 0.98$ (configurable).

### B. Tilt-Compensated Magnetic Heading
Raw magnetometer readings $(B_x, B_y, B_z)$ are calibrated using hard-iron offsets $(V_x, V_y, V_z)$ and soft-iron scale multipliers $(S_x, S_y, S_z)$, then projected into the horizontal plane:

$$B_{x,c} = (B_x - V_x) \cdot S_x, \quad B_{y,c} = (B_y - V_y) \cdot S_y, \quad B_{z,c} = (B_z - V_z) \cdot S_z$$

$$X_h = B_{x,c} \cos\theta + B_{y,c} \sin\phi \sin\theta + B_{z,c} \cos\phi \sin\theta$$
$$Y_h = B_{y,c} \cos\phi - B_{z,c} \sin\phi$$

$$\text{Heading} (\psi) = \text{atan2}(-Y_h, X_h) \times \frac{180}{\pi} \pmod{360^\circ}$$

### C. Fin-Aligned Drift Sector Calculation
1. Mechanical current-alignment fins align the vessel $+X$ axis with the ocean current vector $\vec{V}_{\text{current}}$.
2. The magnetometer directly measures this aligned orientation $\psi_{\text{fin}}$.
3. Short-term IMU motion direction $\psi_{\text{imu}}$ is extracted from horizontal acceleration components:

$$a_{N} = a_x \cos\theta \cos\psi - a_y \sin\psi + a_z \sin\theta \cos\psi$$
$$a_{E} = a_x \cos\theta \sin\psi + a_y \cos\psi + a_z \sin\theta \sin\psi$$

$$\psi_{\text{imu}} = \text{atan2}(a_E, a_N) \times \frac{180}{\pi}$$

4. The estimated drift bearing $\theta_{\text{drift}}$ is computed via weighted circular angular fusion:

$$\theta_{\text{drift}} = \text{atan2}\left( w_{\text{mag}} \sin\psi_{\text{fin}} + w_{\text{imu}} \sin\psi_{\text{imu}}, w_{\text{mag}} \cos\psi_{\text{fin}} + w_{\text{imu}} \cos\psi_{\text{imu}} \right)$$

where default weights are $w_{\text{mag}} = 0.80, w_{\text{imu}} = 0.20$.
The uncertainty sector half-angle $\Delta\theta$ defaults to $30.0^\circ$, producing a $60.0^\circ$ directional search cone.

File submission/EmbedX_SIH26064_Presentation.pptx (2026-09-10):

## SMART INDIA HACKATHON 2026

TITLE PAGE

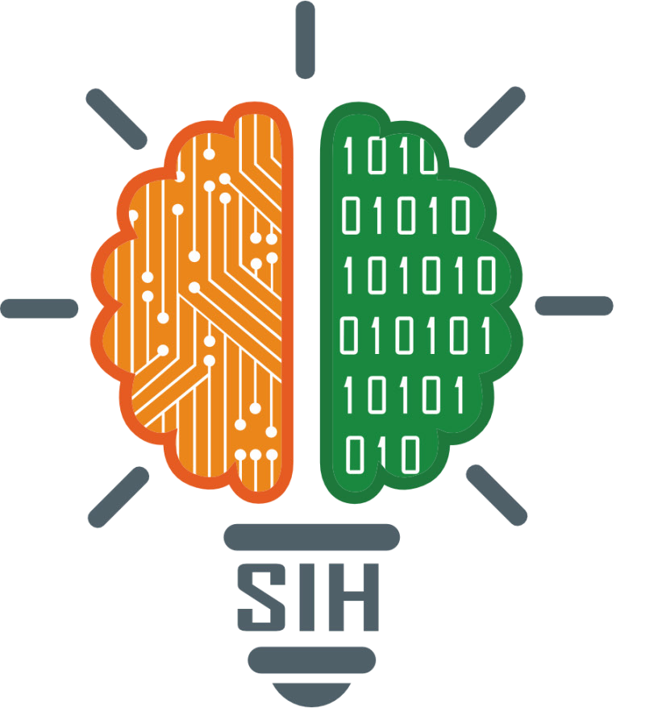
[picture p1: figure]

- Problem Statement ID – SIH26064
- Problem Statement Title - Low-Cost Deployable Seafloor Metal Detection Sensor for Ocean Resource Exploration
- Theme- Robotics and Drones
- PS Category- Hardware
- Team Name (Registered on portal) - EmbedX

## Low-Cost Deployable Seafloor Metal Detection & Localization

SIH 2026

EmbedX

A compact deployable package combining PI metal sensing, seawater temperature, magnetic heading and motion/aGitude to detect and prioritize seabed anomalies.

Proposed Solution:

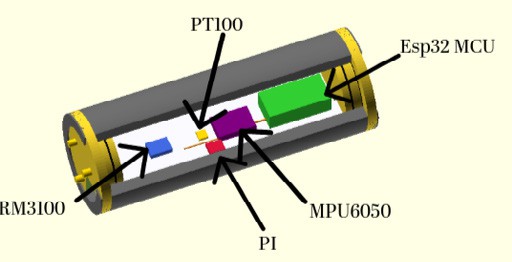
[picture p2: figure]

Deploy
Surface GPS coordinates are recorded.

ESP32 synchronizes and logs sensor data for post-recovery analysis and GIS mapping.

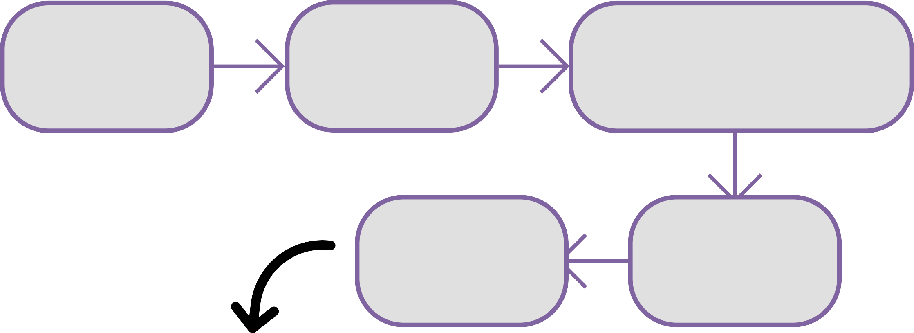
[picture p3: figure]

Sense
Sensor package collects synchronized measurements

PI Coil s conductive / metallic response PT100 s seawater temperature
RM3100 s magnetic heading MPU6050 s motion & aGitude

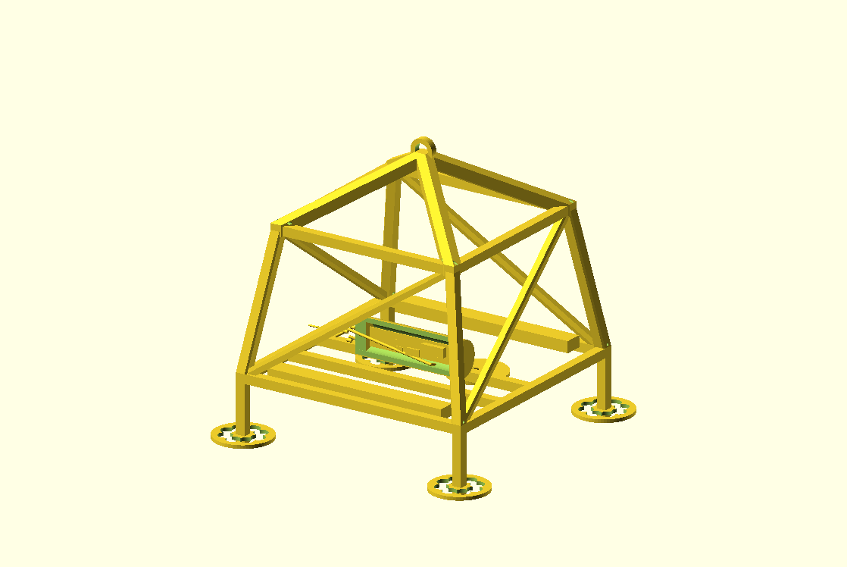
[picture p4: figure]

Payload carrier and lander

Analyze
Filter s extract features s detect anomaly s combine evidence

ESP32 timestamps and logs all sensor data

MAP
GIS heatmap s
multi-station overlap s candidate region

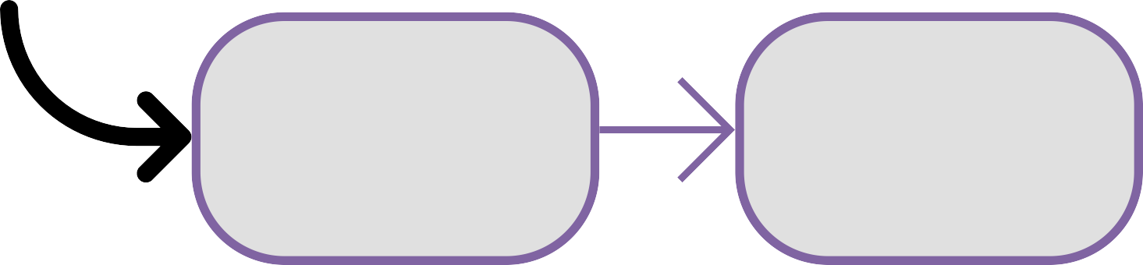
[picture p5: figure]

LOCALIZE
GPS + driŁ bearing s directional uncertainty sector

## TECHNICAL APPROACH

- HOW THE SYSTEM WORKS
- Sensor Acquisition: Multi-sensor suite captures magnetic, metallic, temperature, motion and timestamp data.
- ESP32 Edge Processing: ESP32 collects, synchronizes and locally logs the raw sensor readings during deployment.
- Telemetry: After recovery, logged data is transferred via Wi-Fi in CSV/JSON format for processing.
- Data Analysis: Raw signals undergo preprocessing → feature extraction → anomaly detection → evidence-based classification.
- Geo-Spatial Localization: Magnetic heading, IMU motion data and current-aligned fins are fused to estimate the probable drift direction and uncertainty.
- GIS Visualization: Detected anomalies are mapped with heatmaps and directional uncertainty sectors and overlaid with available seafloor topography.
- Priority Search Region: Intersecting information from multiple deployments narrows the probable target area, guiding efficient ROV/field investigation.

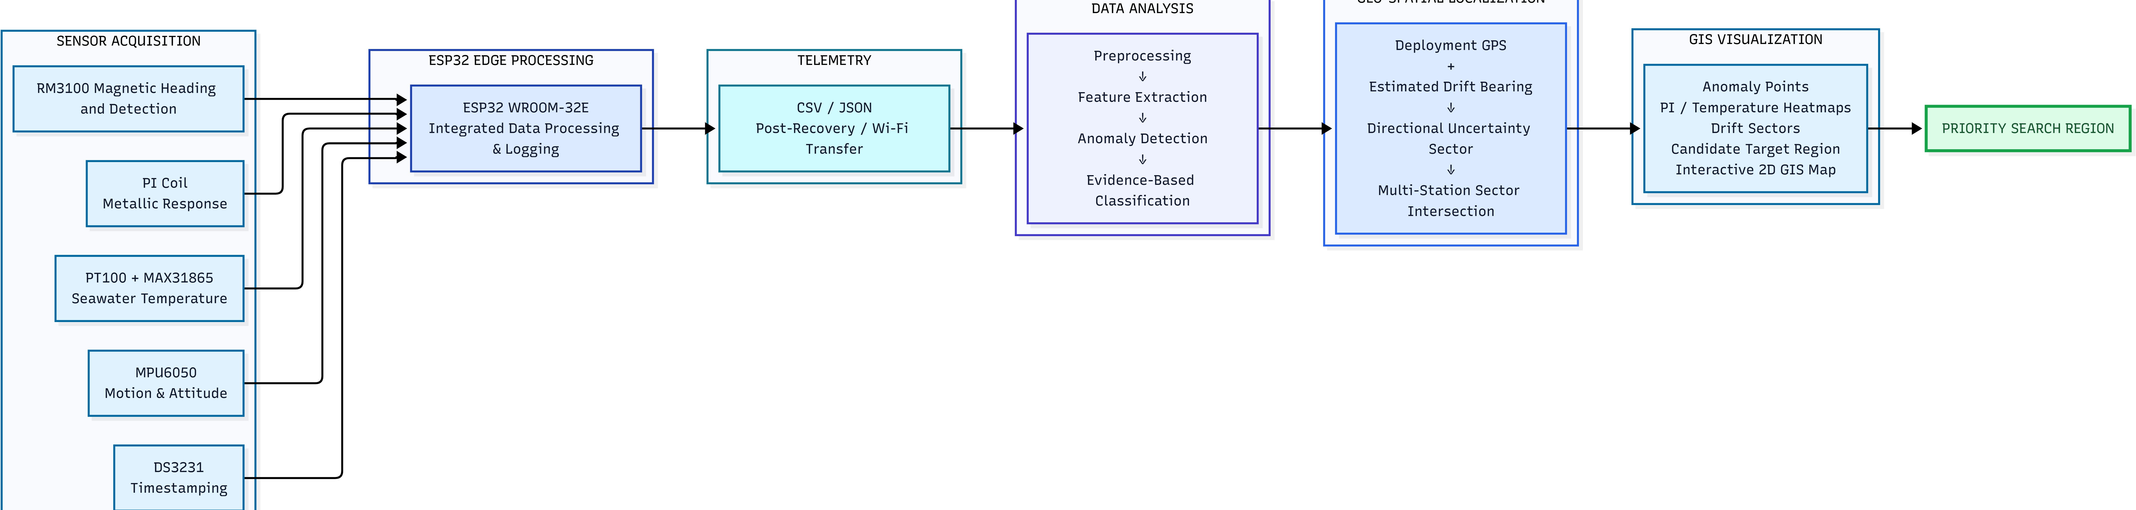
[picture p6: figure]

EmbedX

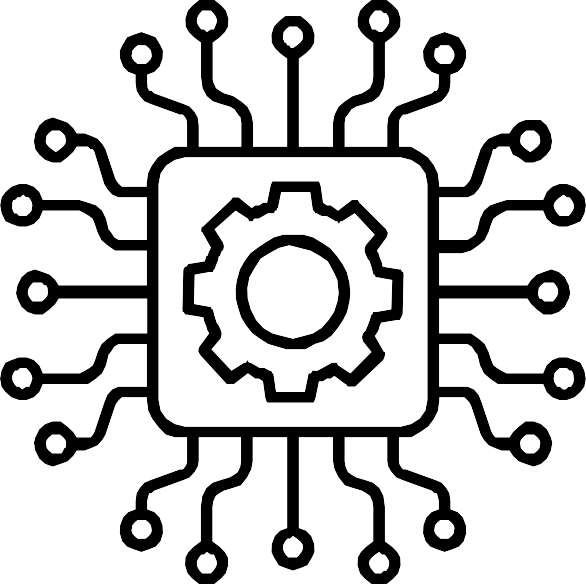
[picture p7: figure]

## FEASIBILITY AND VIABILITY

EmbedX

TECHNICALLY FEASIBLE
- Low-cost COTS sensors: ESP32, MPU6050, RM3100, PT100 and RTC.
- Local data logging: Sensor operates underwater without requiring continuous communication.
- Post-recovery Wi-Fi transfer: Data can be uploaded after retrieval.
- Pressure-resistant torpedo-style housing enables deep-sea deployment.
- Modular design: Sensors can be calibrated/replaced independently.
KEY CHALLENGES
- Underwater drift: Deployment GPS ≠ actual seabed sensor position.
- Magnetic interference: PI coil, battery and magnetometer can interfere with each other.
- Accelerometer drift: IMU cannot reliably estimate the full 400 m displacement by double integration.
- Deep-sea conditions: Pressure, waterproofing and seawater exposure.
- PI coil optimization: Final coil design and detection performance require prototype testing.
MITIGATION STRATEGY
- Drift → Estimate probable drift direction using RM3100 + MPU6050 + mechanical fins.
- Magnetic interference → Physically separate magnetometer and PI coil + time-multiplex operation.
- IMU error → Use IMU for short-term motion, not long-term dead reckoning.
- Water/pressure → Sealed pressure-resistant housing + protected seawater interface for PT100.
- Uncertainty → Represent location as a directional sector, validated through prototype drift tests.

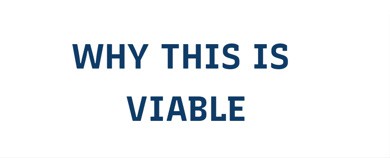
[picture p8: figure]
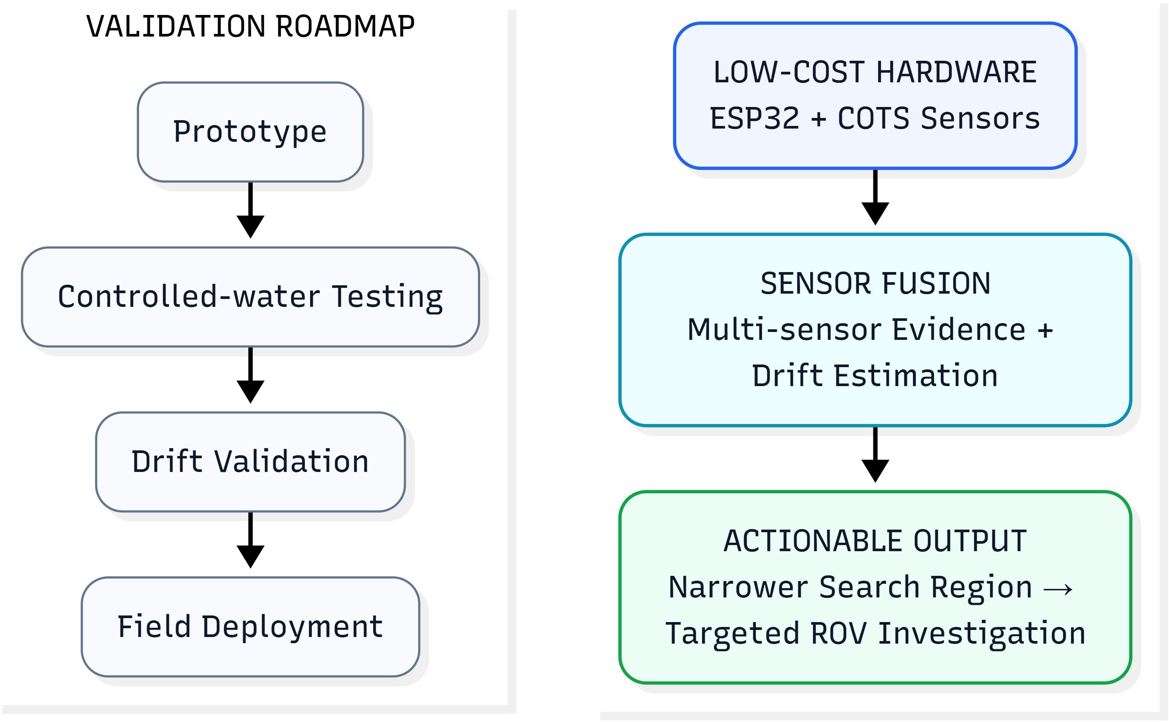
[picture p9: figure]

## IMPACT AND BENEFITS

EmbedX

1. FASTER EXPLORATION
  - Rapid screening of seabed anomalies
  - Helps prioritize promising regions before detailed investigation
  - Reduces time spent investigating low-value anomalies

2. COST SAVINGS
  - Low-cost deployable sensor platform
  - Reduces unnecessary ROV investigations
  - Enables multiple screening deployments during a survey

3. DEEP-SEA RESOURCE MAPPING
  - Identifies magnetic, metallic and thermal anomalies
  - Combines sensor readings with existing seafloor topography
  - Produces spatially constrained candidate regions

4. STRATEGIC BENEFIT
  - Supports Indian deep-ocean resource exploration
  - Provides an indigenous, modular sensing approach
  - Can complement existing MoES/NCPOR survey infrastructure

DETECT

PRIORITIZE

INVESTIGATE

## RESEARCH AND REFERENCES

EmbedX

Research:
- Drone (https://www.researchgate.net/profile/Hamish-Biggs/publication/361598754_Drone_Flow_User_Guide_v11_-_River_remote_sensing_and_surface_velocimetry/links/62bbbfb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) (https://www.researchgate.net/profile/Hamish-Biggs/publication/361598754_Drone_Flow_User_Guide_v11_-_River_remote_sensing_and_surface_velocimetry/links/62bbbfb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)Flow (https://www.researchgate.net/profile/Hamish-Biggs/publication/361598754_Drone_Flow_User_Guide_v11_-_River_remote_sensing_and_surface_velocimetry/links/62bbbfb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) (https://www.researchgate.net/profile/Hamish-Biggs/publication/361598754_Drone_Flow_User_Guide_v11_-_River_remote_sensing_and_surface_velocimetry/links/62bbbfb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)User (https://www.researchgate.net/profile/Hamish-Biggs/publication/361598754_Drone_Flow_User_Guide_v11_-_River_remote_sensing_and_surface_velocimetry/links/62bbbfb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) (https://www.researchgate.net/profile/Hamish-Biggs/publication/361598754_Drone_Flow_User_Guide_v11_-_River_remote_sensing_and_surface_velocimetry/links/62bbbfb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)Guide (https://www.researchgate.net/profile/Hamish-Biggs/publication/361598754_Drone_Flow_User_Guide_v11_-_River_remote_sensing_and_surface_velocimetry/links/62bbbfb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)
- A (https://www.mdpi.com/2077-1312/12/2/200/pdf?version=1705992680) (https://www.mdpi.com/2077-1312/12/2/200/pdf?version=1705992680)Low- (https://www.mdpi.com/2077-1312/12/2/200/pdf?version=1705992680)Cost (https://www.mdpi.com/2077-1312/12/2/200/pdf?version=1705992680) (https://www.mdpi.com/2077-1312/12/2/200/pdf?version=1705992680)and (https://www.mdpi.com/2077-1312/12/2/200/pdf?version=1705992680) (https://www.mdpi.com/2077-1312/12/2/200/pdf?version=1705992680)High- (https://www.mdpi.com/2077-1312/12/2/200/pdf?version=1705992680)Precision (https://www.mdpi.com/2077-1312/12/2/200/pdf?version=1705992680) (https://www.mdpi.com/2077-1312/12/2/200/pdf?version=1705992680)Underwater (https://www.mdpi.com/2077-1312/12/2/200/pdf?version=1705992680) (https://www.mdpi.com/2077-1312/12/2/200/pdf?version=1705992680)Integrated (https://www.mdpi.com/2077-1312/12/2/200/pdf?version=1705992680) (https://www.mdpi.com/2077-1312/12/2/200/pdf?version=1705992680)Navigation (https://www.mdpi.com/2077-1312/12/2/200/pdf?version=1705992680) (https://www.mdpi.com/2077-1312/12/2/200/pdf?version=1705992680)System (https://www.mdpi.com/2077-1312/12/2/200/pdf?version=1705992680)
- A (https://www.mdpi.com/1424-8220/24/19/6299/pdf?version=1727597857) (https://www.mdpi.com/1424-8220/24/19/6299/pdf?version=1727597857)Multi- (https://www.mdpi.com/1424-8220/24/19/6299/pdf?version=1727597857)Sensor (https://www.mdpi.com/1424-8220/24/19/6299/pdf?version=1727597857) (https://www.mdpi.com/1424-8220/24/19/6299/pdf?version=1727597857)Fusion (https://www.mdpi.com/1424-8220/24/19/6299/pdf?version=1727597857) (https://www.mdpi.com/1424-8220/24/19/6299/pdf?version=1727597857)Underwater (https://www.mdpi.com/1424-8220/24/19/6299/pdf?version=1727597857) (https://www.mdpi.com/1424-8220/24/19/6299/pdf?version=1727597857)Localization (https://www.mdpi.com/1424-8220/24/19/6299/pdf?version=1727597857) (https://www.mdpi.com/1424-8220/24/19/6299/pdf?version=1727597857)Method (https://www.mdpi.com/1424-8220/24/19/6299/pdf?version=1727597857) (https://www.mdpi.com/1424-8220/24/19/6299/pdf?version=1727597857)Based (https://www.mdpi.com/1424-8220/24/19/6299/pdf?version=1727597857) (https://www.mdpi.com/1424-8220/24/19/6299/pdf?version=1727597857)on (https://www.mdpi.com/1424-8220/24/19/6299/pdf?version=1727597857) (https://www.mdpi.com/1424-8220/24/19/6299/pdf?version=1727597857)Unscented (https://www.mdpi.com/1424-8220/24/19/6299/pdf?version=1727597857) (https://www.mdpi.com/1424-8220/24/19/6299/pdf?version=1727597857)Kalman (https://www.mdpi.com/1424-8220/24/19/6299/pdf?version=1727597857) (https://www.mdpi.com/1424-8220/24/19/6299/pdf?version=1727597857)Filter (https://www.mdpi.com/1424-8220/24/19/6299/pdf?version=1727597857) (https://www.mdpi.com/1424-8220/24/19/6299/pdf?version=1727597857)on (https://www.mdpi.com/1424-8220/24/19/6299/pdf?version=1727597857) (https://www.mdpi.com/1424-8220/24/19/6299/pdf?version=1727597857)Manifolds (https://www.mdpi.com/1424-8220/24/19/6299/pdf?version=1727597857)
Hardware References:
- ESP32- (https://documentation.espressif.com/esp32-wroom-32e_esp32-wroom-32ue_datasheet_en.html)WROOM- (https://documentation.espressif.com/esp32-wroom-32e_esp32-wroom-32ue_datasheet_en.html)32E (https://documentation.espressif.com/esp32-wroom-32e_esp32-wroom-32ue_datasheet_en.html) (https://documentation.espressif.com/esp32-wroom-32e_esp32-wroom-32ue_datasheet_en.html)Datasheet (https://documentation.espressif.com/esp32-wroom-32e_esp32-wroom-32ue_datasheet_en.html)
- RM3100 (https://pnicorp.com/wp-content/uploads/RM3100-Sensor-Suite-User-Manual-R07-1.pdf) (https://pnicorp.com/wp-content/uploads/RM3100-Sensor-Suite-User-Manual-R07-1.pdf)Datasheet (https://pnicorp.com/wp-content/uploads/RM3100-Sensor-Suite-User-Manual-R07-1.pdf)
- MPU6050 Datasheet
- MAX31865 (https://www.analog.com/en/products/max31865.html) (https://www.analog.com/en/products/max31865.html)Datasheet (https://www.analog.com/en/products/max31865.html)
- PT100 (https://www.renesas.com/en/document/apn/cm-397-pt1001000-rtd-interface) (https://www.renesas.com/en/document/apn/cm-397-pt1001000-rtd-interface)Datasheet (https://www.renesas.com/en/document/apn/cm-397-pt1001000-rtd-interface)
- (https://ietresearch.onlinelibrary.wiley.com/doi/full/10.1049/el.2014.3895)PI (https://ietresearch.onlinelibrary.wiley.com/doi/full/10.1049/el.2014.3895) (https://ietresearch.onlinelibrary.wiley.com/doi/full/10.1049/el.2014.3895)Detection (https://ietresearch.onlinelibrary.wiley.com/doi/full/10.1049/el.2014.3895) (https://ietresearch.onlinelibrary.wiley.com/doi/full/10.1049/el.2014.3895)Reference (https://ietresearch.onlinelibrary.wiley.com/doi/full/10.1049/el.2014.3895)
Implementation & Documentation:
- GitHub (https://github.com/smarthsharma07/Seafloor-Metal-Detection-EmbedX) (https://github.com/smarthsharma07/Seafloor-Metal-Detection-EmbedX)Repository (https://github.com/smarthsharma07/Seafloor-Metal-Detection-EmbedX) (https://github.com/smarthsharma07/Seafloor-Metal-Detection-EmbedX)

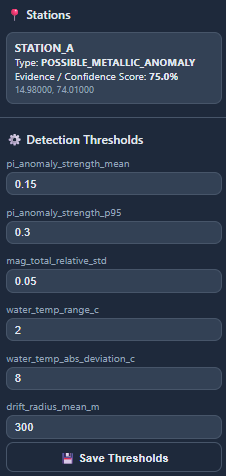
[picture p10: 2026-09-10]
assets/screenshots/detection-thresholds.png

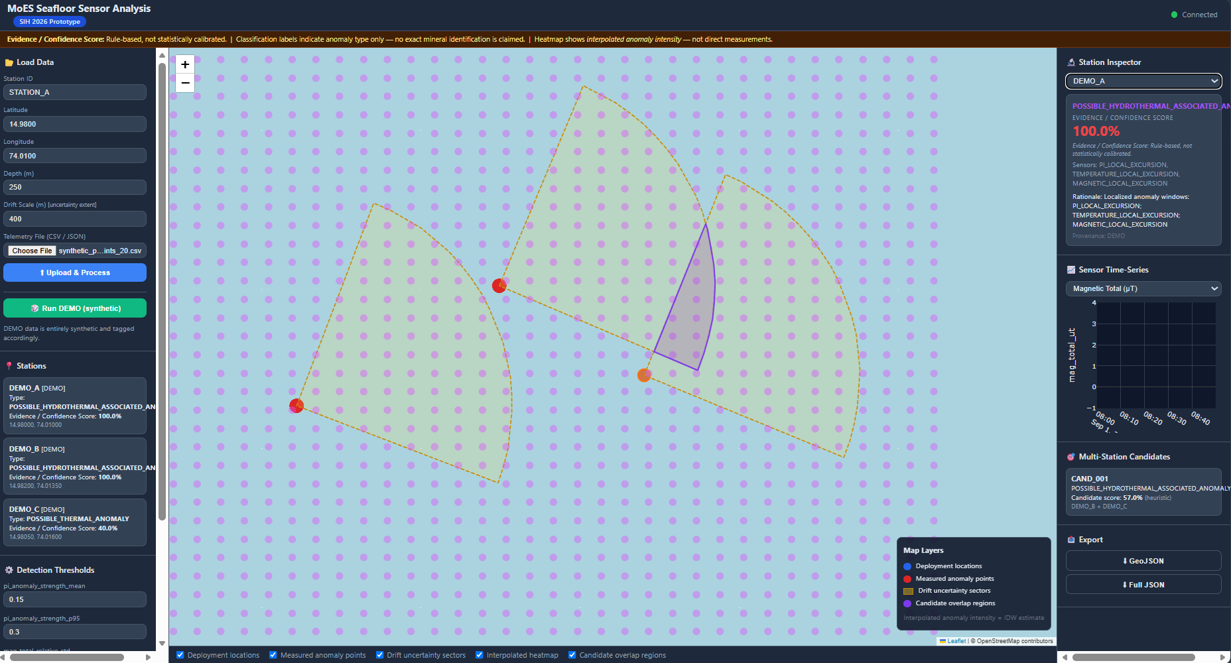
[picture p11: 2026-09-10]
assets/screenshots/analysis-dashboard-synthetic.png 3.png

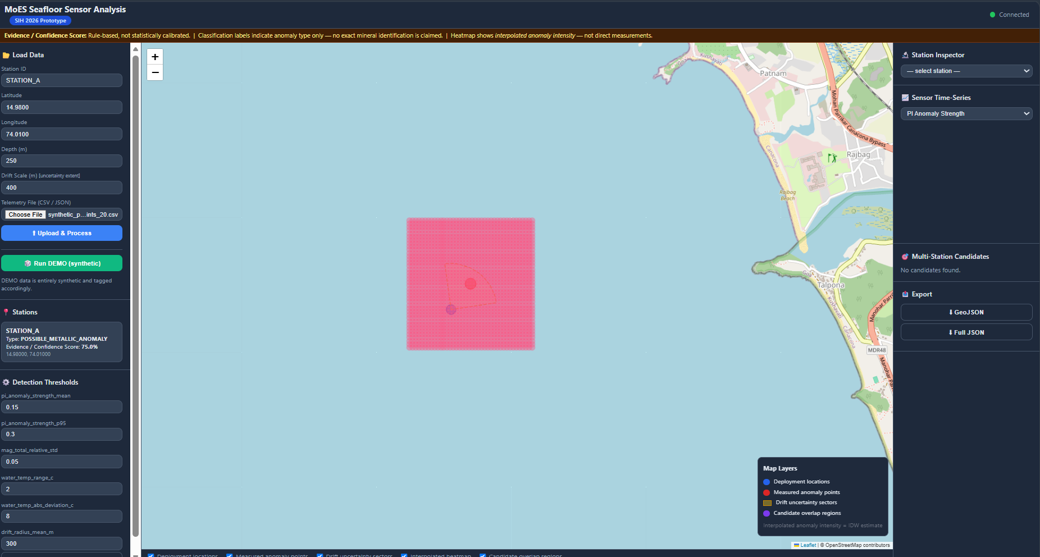
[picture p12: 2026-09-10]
assets/screenshots/map-gis.png

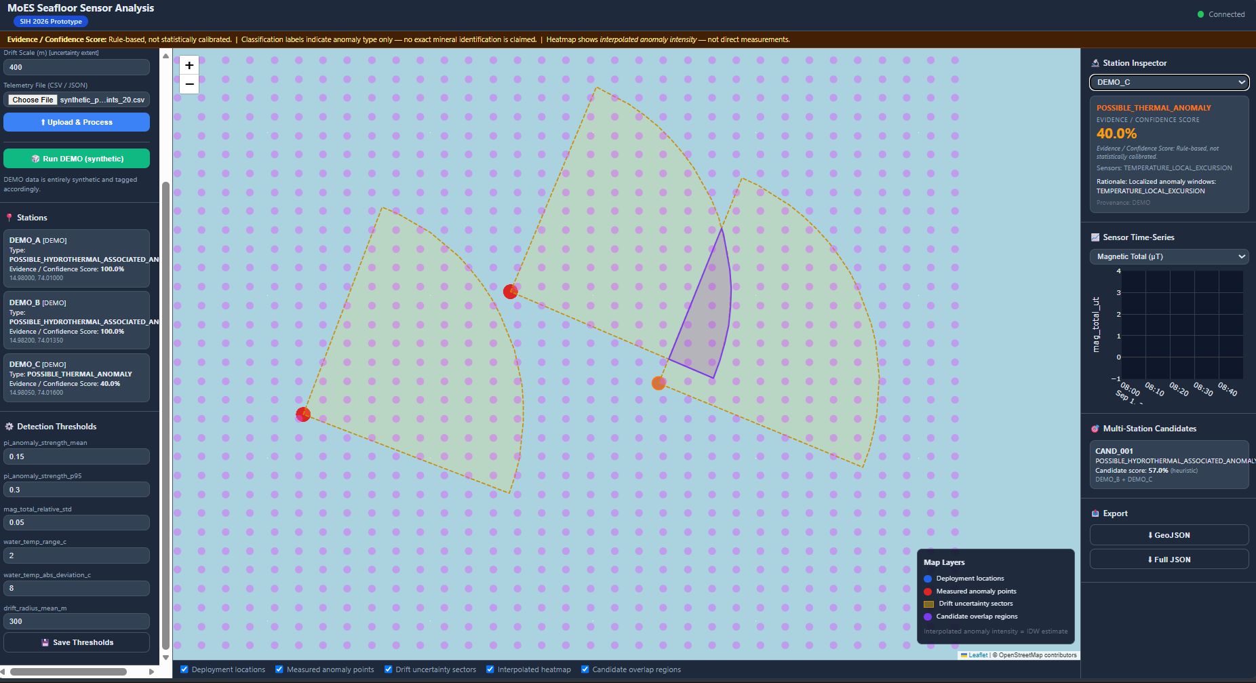
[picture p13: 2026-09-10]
assets/screenshots/analysis-dashboard-synthetic.png 5.png

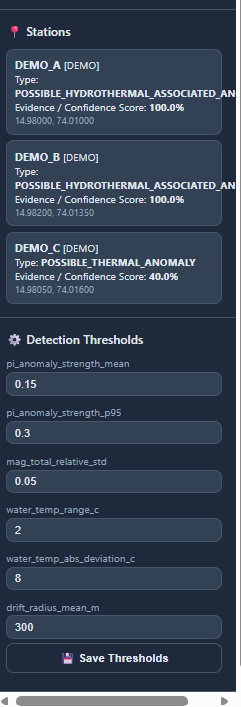
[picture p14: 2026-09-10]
assets/screenshots/detection-thresholds01.png

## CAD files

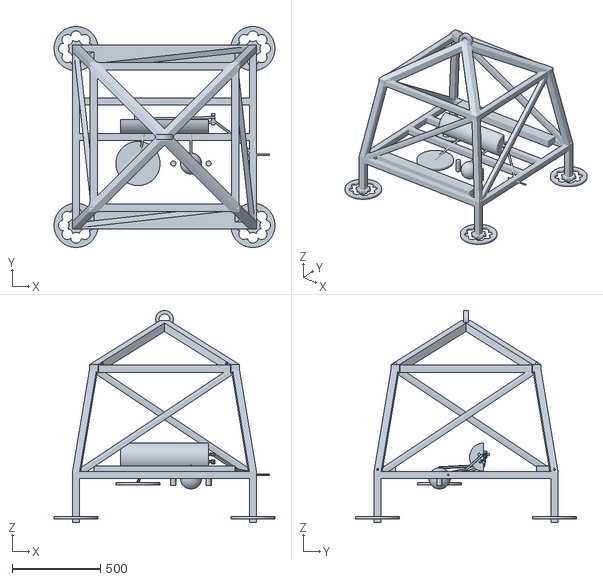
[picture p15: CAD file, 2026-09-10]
assets/vessel_schematics_cad/Payload carrier and lander_26064.stl
1250.0 x 1250.0 x 1200.0

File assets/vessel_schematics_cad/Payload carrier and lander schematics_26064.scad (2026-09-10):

// ---------------------------------------------------------
// Tethered Deep-Sea Drop-Frame - Complete OpenSCAD Model
// (Battery operated, internal data logging, winch-deployed)
// ---------------------------------------------------------

$fn = 64; // High resolution rendering

// --- GLOBALS & DIMENSIONS ---
w = 40;            // Square tubing width (mm)
L = 1000;          // Frame base width (mm)
H = 600;           // Main frame height (Lowered for tether stability)
h_leg = 250;       // Mud legs height (mm)
tL = 800;          // Top platform width (mm)

// --- GEOMETRIC POINTS ---
// Mud feet locations (Z=0)
l00 = [-L/2, -L/2, 0]; l10 = [ L/2, -L/2, 0]; l11 = [ L/2, L/2, 0]; l01 = [-L/2, L/2, 0];

// Main chassis base (Z=h_leg)
b00 = [-L/2, -L/2, h_leg]; b10 = [ L/2, -L/2, h_leg]; 
b11 = [ L/2,  L/2, h_leg]; b01 = [-L/2,  L/2, h_leg];

// Main chassis top platform
t00 = [-tL/2, -tL/2, h_leg+H]; t10 = [ tL/2, -tL/2, h_leg+H];
t11 = [ tL/2,  tL/2, h_leg+H]; t01 = [-tL/2,  tL/2, h_leg+H];

// Apex Lifting Point
apex = [0, 0, h_leg+H+250];

// --- UTILITY MODULES ---
module strut(p1, p2, width) {
    color("silver")
    hull() {
        translate(p1) cube([width, width, width], center=true);
        translate(p2) cube([width, width, width], center=true);
    }
}

module cable(p1, p2, p3) {
    color("darkorange") {
        hull() { translate(p1) sphere(d=12); translate(p2) sphere(d=12); }
        hull() { translate(p2) sphere(d=12); translate(p3) sphere(d=12); }
    }
}

// --- MAIN COMPONENTS ---

// 1. Reinforced Chassis
module heavy_frame() {
    difference() {
        union() {
            // Legs to feet
            strut(l00, b00, w); strut(l10, b10, w); strut(l11, b11, w); strut(l01, b01, w);
            // Lower perimeter
            strut(b00, b10, w); strut(b10, b11, w); strut(b11, b01, w); strut(b01, b00, w);
            // Upper perimeter
            strut(t00, t10, w); strut(t10, t11, w); strut(t11, t01, w); strut(t01, t00, w);
            // Vertical pillars
            strut(b00, t00, w); strut(b10, t10, w); strut(b11, t11, w); strut(b01, t01, w);
            // Diagonal bracing (tension members)
            strut(b00, t10, w/1.5); strut(b10, t11, w/1.5); 
            strut(b11, t01, w/1.5); strut(b01, t00, w/1.5);
            // Internal payload mounting rails
            strut([-L/2, 200, h_leg], [L/2, 200, h_leg], w);
            strut([-L/2, 0, h_leg], [L/2, 0, h_leg], w);
            // Triangulated A-Frame Lifting Bridle
            strut(t00, apex, w*1.2); strut(t10, apex, w*1.2);
            strut(t11, apex, w*1.2); strut(t01, apex, w*1.2);
        }
        // Weep holes for free-flooding
        for (p = [b00, b10, b11, b01, t00, t10, t11, t01]) {
            translate(p + [0,0,30]) rotate([0,90,0]) cylinder(h=w*3, d=12, center=true);
        }
    }
}

// 2. Mud Feet (Geometric anti-suction)
module mud_feet() {
    color("silver")
    for (pos = [l00, l10, l11, l01]) {
        translate(pos) {
            difference() {
                cylinder(h=15, d=250, center=false);
                for (a = [0:45:315]) {
                    rotate([0, 0, a]) translate([70, 0, -5]) cylinder(h=30, d=60);
                }
            }
        }
    }
}

// 3. Static Ballast (Bolted to bottom rails to keep tether taut)
module static_ballast() {
    color("darkslategray")
    for (y = [-L/2+60, L/2-60]) {
        translate([0, y, h_leg + 25])
        cube([800, 80, 50], center=true);
    }
}

// 4. Heavy-Duty Lifting Shackle
module lifting_shackle() {
    translate(apex + [0, 0, 30])
    rotate([90, 0, 0]) {
        color("dimgray") difference() {
            cylinder(h=30, d=100, center=true);
            cylinder(h=35, d=60, center=true);
            translate([0, -50, 0]) cube([110, 50, 40], center=true);
        }
        // Shackle Pin
        color("silver") translate([0, -20, 0]) cylinder(h=50, d=20, center=true);
    }
}

// 5. Electronics Housing (Battery, SD Logging, MCU, IMU)
module electronics_cylinder() {
    c_len = 500; c_od = 160; c_id = 120;
    
    translate([0, 100, h_leg + 100]) 
    rotate([0, 90, 0]) {
        // Main cylinder with cutaway
        color("dimgray") difference() {
            cylinder(h=c_len, d=c_od, center=true);
            cylinder(h=c_len + 10, d=c_id, center=true);
            translate([0, c_od/2, 0]) cube([c_od, c_od, c_len+20], center=true); // Cutaway
        }
        
        // End-caps with O-rings
        color("silver")
        for (z = [-c_len/2 + 25, c_len/2 - 25]) {
            translate([0, 0, z]) {
                difference() {
                    union() {
                        cylinder(h=50, d=c_id - 1, center=true);
                        translate([0, 0, (z > 0 ? 15 : -15)]) cylinder(h=20, d=c_od, center=true);
                    }
                    translate([0, c_od/2, 0]) cube([c_od, c_od, 100], center=true);
                }
            }
        }
        
        // Internal Sled (Dry payload)
        color("dodgerblue") translate([0, -15, 0]) cube([80, 5, c_len - 120], center=true);
        
        // Component Layout
        color("limegreen") translate([-15, 10, -120]) cube([40, 20, 100], center=true); // Battery
        color("purple") translate([15, 5, -20]) cube([30, 8, 60], center=true);     // MCU
        color("red") translate([15, 5, 40]) cube([20, 4, 30], center=true);         // MicroSD
        color("gold") translate([-15, 5, 60]) cube([15, 3, 15], center=true);       // IMU
    }
}

// 6. External Sensors & Cables
module sensors_and_cables() {
    // Pulse Induction (PI) Coil
    color("black") translate([-150, -150, h_leg - 50]) cylinder(h=15, d=250, center=true);
    
    // PT100 Probe
    color("silver") translate([L/2 + 20, -100, h_leg]) rotate([0, 90, 0]) cylinder(h=150, d=8, center=true);
    
    // Downward Camera & LEDs
    color("lightblue", 0.4) translate([150, -150, h_leg - 20]) sphere(d=120);
    color("black") translate([150, -150, h_leg - 20]) cylinder(h=60, d=40, center=true);
    color("white") for (dx = [50, 250]) translate([dx, -150, h_leg - 20]) cylinder(h=80, d=30, center=true);
    
    // Bulkhead Penetrators & Wiring
    color("gold") translate([275, 100, h_leg + 100]) rotate([0, 90, 0])
    for (a = [0, 120, 240]) {
        rotate([0, 0, a]) translate([30, 0, 0]) cylinder(h=20, d=15, center=true);
    }
    
    cable([-150, -150, h_leg - 40], [-100, 100, h_leg + 50], [280, 110, h_leg + 120]);
    cable([150, -150, h_leg + 40], [150, 50, h_leg + 50], [280, 90, h_leg + 80]);
    cable([L/2, -100, h_leg + 10], [L/2 - 100, 0, h_leg + 30], [280, 90, h_leg + 110]);
}

// --- ASSEMBLE MODEL ---
heavy_frame();
mud_feet();
static_ballast();
lifting_shackle();
electronics_cylinder();
sensors_and_cables();

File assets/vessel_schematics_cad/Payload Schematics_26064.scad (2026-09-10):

// ---------------------------------------------------------
// Deep-Sea Benthic Lander - Pressure Housing & Sled
// ---------------------------------------------------------

$fn = 100; // High resolution for smooth O-rings and cylinders

// --- DIMENSIONS ---
c_len = 450;       // Total length of the pressure tube (mm)
c_od = 160;        // Outer Diameter (mm) - 20mm thick walls (7075-T6)
c_id = 120;        // Inner Diameter (mm)

// Sled Geometry (Derived graphically via chord length)
// Dropping the sled 25mm below the center axis creates a chord width of ~114mm.
sled_z_offset = -25; 
sled_w = 110;      // Slightly undersized for clearance
sled_len = 380;    // Length of the acrylic mounting board
sled_thick = 5;    // Thickness of the sled board

// --- MODULES ---

// 1. The Main 7075-T6 Aluminum Tube (With Cutaway)
module pressure_tube() {
    color("dimgray")
    difference() {
        // Outer tube
        rotate([0, 90, 0]) cylinder(h=c_len, d=c_od, center=true);
        // Inner bore
        rotate([0, 90, 0]) cylinder(h=c_len + 10, d=c_id, center=true);
        
        // 120-degree cutaway to view the internal sled
        translate([0, c_od/2 + 10, c_od/2 + 10])
        cube([c_len + 20, c_od, c_od], center=true);
    }
}

// 2. Piston End-Caps with Radial Seals
module end_caps() {
    for (x = [-c_len/2 + 25, c_len/2 - 25]) {
        translate([x, 0, 0]) {
            rotate([0, 90, 0]) {
                difference() {
                    union() {
                        // The inner plug that slides into the bore
                        cylinder(h=40, d=c_id - 0.5, center=true);
                        // The outer retaining flange
                        translate([0, 0, (x > 0 ? 15 : -15)]) 
                        cylinder(h=15, d=c_od, center=true);
                    }
                    // Cutaway slice to match the tube
                    translate([c_od/2 + 10, c_od/2 + 10, 0])
                    cube([c_od, c_od, 100], center=true);
                }
                
                // Viton O-Rings (Black)
                color("black")
                for (g = [-8, 8]) {
                    translate([0, 0, g])
                    rotate_extrude()
                    translate([(c_id-4)/2, 0, 0]) circle(d=4.5);
                }
            }
        }
    }
    
    // Front End-Cap Bulkhead Penetrators (Gold)
    // Placed only on the front cap (x > 0)
    color("gold")
    translate([c_len/2 - 5, 0, 0])
    rotate([0, 90, 0]) {
        for (a = [0, 120, 240]) {
            rotate([0, 0, a])
            translate([35, 0, 0])
            cylinder(h=30, d=12, center=true);
        }
    }
}

// 3. The Electronics Sled and Runner Rails
module electronics_sled() {
    translate([0, 0, sled_z_offset]) {
        // Main Delrin/Acrylic Tray
        color("ghostwhite")
        cube([sled_len, sled_w, sled_thick], center=true);
        
        // Side Runner Rails (Smooth standoffs to prevent scratching the bore)
        color("silver")
        for (y = [-sled_w/2, sled_w/2]) {
            translate([0, y, sled_thick/2 + 3])
            rotate([0, 90, 0])
            cylinder(h=sled_len, d=6, center=true);
        }
    }
}

// 4. Component Layout on the Sled
module payload_components() {
    // Base Z height for components sitting on the sled
    z_base = sled_z_offset + (sled_thick / 2);
    
    // REAR: Heavy Li-Ion Battery Pack (Isolated mass)
    color("limegreen")
    translate([-120, 0, z_base + 15])
    cube([100, 50, 30], center=true);
    
    // CENTER-REAR: Microcontroller Unit (MCU)
    color("purple")
    translate([-20, 0, z_base + 6])
    cube([60, 40, 12], center=true);
    
    // CENTER: MPU9250 IMU (Dead center, mounted perfectly flat)
    color("gold")
    translate([30, 0, z_base + 2])
    cube([15, 15, 4], center=true);
    
    // CENTER-FRONT: MicroSD Card Breakout (Adjacent to MCU for short SPI clock lines)
    color("crimson")
    translate([20, 30, z_base + 3])
    cube([25, 20, 6], center=true);
    
    // FRONT: MAX31865 RTD Amplifier (Closest to the front penetrators)
    color("royalblue")
    translate([100, 0, z_base + 4])
    cube([35, 25, 8], center=true);
    
    // Wiring Harness Representation (Orange SPI and Power lines)
    color("darkorange")
    translate([25, 15, z_base + 2])
    rotate([0, 90, 0]) cylinder(h=80, d=2, center=true); // SPI Bus
    
    color("darkorange")
    translate([-60, 10, z_base + 6])
    rotate([0, 90, 0]) cylinder(h=60, d=3, center=true); // Main Power
}

// --- ASSEMBLE MODEL ---
pressure_tube();
end_caps();
electronics_sled();
payload_components();

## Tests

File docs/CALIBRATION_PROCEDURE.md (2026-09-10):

# Calibration Procedure Guide

This document specifies the step-by-step procedures for calibrating the RM3100 magnetometer, MPU6050 IMU, and Pulse Induction baseline engine via the interactive serial CLI.

---

## 1. RM3100 Magnetometer Calibration (`magcal`)

Magnetic fields from onboard batteries, wiring, and structural metals introduce hard-iron bias and soft-iron scale distortion.

### Procedure:
1. Connect the ESP32 to a serial monitor at 115200 baud.
2. Enter command: `magcal`
3. Slowly rotate the sensor package through a continuous 3D figure-8 motion covering all spatial orientations (pitch, roll, yaw) for 15 seconds.
4. The system collects live magnetic samples and records axis extrema ($X_{\min}, X_{\max}, Y_{\min}, Y_{\max}, Z_{\min}, Z_{\max}$).
5. The calibration algorithm calculates the sphere center offset and scale multipliers:
   $$V_x = \frac{X_{\max} + X_{\min}}{2}, \quad \text{Scale}_x = \frac{\Delta_{\text{avg}}}{\Delta_x}$$
6. Offsets and scale multipliers are immediately applied to the active `HeadingCalculator` instance.

---

## 2. MPU6050 IMU Zero-Motion Calibration (`imucal`)

MEMS gyroscopes exhibit zero-rate bias drift, and accelerometers require level calibration.

### Procedure:
1. Place the sensor package on a stable, level surface.
2. Enter command: `imucal`
3. Keep the unit completely motionless for 4 seconds while 200 samples are accumulated.
4. The system calculates zero-rate gyro offsets and accelerometer bias (adjusting $Z$-axis for $1g = 9.80665\,\text{m}/\text{s}^2$).
5. Calibration offsets are applied to the active `MPU6050Sensor` driver.

---

## 3. Pulse Induction Baseline Zeroing (`pical`)

Background mineralized seabed soils and ambient electromagnetic conditions affect the zero-metal decay curve.

### Procedure:
1. Position the sensor in an environment free of metallic target objects.
2. Enter command: `pical`
3. The system resets the decay baseline to zero and executes a sequence of 10 pulse bursts to establish the background decay level.

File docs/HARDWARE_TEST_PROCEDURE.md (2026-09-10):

# Hardware Bring-Up & Bench Test Procedure

This document provides step-by-step physical bench testing procedures for hardware engineers bringing up the sensor electronics.

---

## 1. Safety & Power Pre-Checks
1. **Visual Continuity Check:** Inspect all soldering on EXT1 and EXT2 headers. Ensure no shorts exist between 5V/3.3V power pins and GND.
2. **Voltage Level Verification:** Supply 5V to the main power terminal. Measure ESP32 3.3V rail with a multimeter to ensure $3.30\,\text{V} \pm 0.05\,\text{V}$.
3. **Ground Continuity:** Confirm zero resistance between sensor grounds, ESP32 GND pins, and MOSFET source.

---

## 2. Step-by-Step Bench Bring-Up Sequence

### Step 1: Serial CLI Verification
- Connect ESP32 USB cable. Open serial terminal at 115200 baud.
- Verify boot log displays self-test table:
  ```
  ========================================
  SYSTEM SELF-TEST DIAGNOSTIC TABLE
  ========================================
  MPU6050        [OK]   Addr: 0x69
  DS3231         [OK]   Addr: 0x68
  MAX31865       [OK]   CS: GPIO5, Rref: 430.0
  RM3100         [OK]   CS: GPIO4
  PI DRIVER      [READY] Gate: GPIO33, ADC: GPIO32
  LOGGER         [READY] LittleFS Mounted
  WIFI RECOVERY  [READY] AP Mode Standing By
  ========================================
  ```

### Step 2: I2C Bus Diagnostics
- Type `i2cscan`. Confirm devices detected at `0x68` (DS3231) and `0x69` (MPU6050).
- If MPU6050 appears at `0x68`, `AD0` pin is grounded. Wire `AD0` to `3.3V` immediately to prevent collision!

### Step 3: Sensor Data Verification
- Type `readimu`. Verify valid acceleration (~$9.81\,m/s^2$ on Z axis) and gyro values.
- Type `readtemp`. Verify RTD temperature (~$20^\circ C - 30^\circ C$ ambient).
- Type `readmag`. Verify magnetic vector (~$20-60\,\mu T$ magnitude).
- Type `readrtc`. Verify RTC timestamp matches system date/time.

### Step 4: Pulse Induction Bench Test
- Type `piread`. Verify baseline decay curve readings.
- Bring a metallic object (steel key or coin) near the PI coil.
- Type `piread`. Verify `pi_strength` increases significantly and `pi_detected` flips to `1`.

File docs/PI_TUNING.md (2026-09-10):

# Pulse Induction (PI) Tuning & Waveform Guide

This document details the operation, parameter tuning, baseline tracking, and anomaly detection algorithms of the parameterized Pulse Induction (PI) metal detector module.

---

## 1. Timing Sequence & Waveform

```
                      PI PULSE TIMING SEQUENCE
                      
MOSFET GATE (GPIO33):
      +-----------------+
      |                 |
------+                 +----------------------------------------
      <-- pulse_width -->
      (150 us default)

COIL DECAY RESPONSE (GPIO32):
----+\                                 
      \  (Switching Transient)         
       \=======+                       
               \                       
                +--. (Sample Window: 16 microsecond samples)
                    `----------------. 
      <------->                        
      settling_delay                   
      (30 us default)                  
      
      <------------------------------->
              pulse_period (1000 us default)
```

---

## 2. Parameter Matrix

| Parameter Macro | Provisional Default | Unit | Description | Bench Calibration Notes |
| :--- | :--- | :--- | :--- | :--- |
| `PI_PULSE_WIDTH_US` | `150` | $\mu\text{s}$ | Duration MOSFET gate is held HIGH to energize coil. | Increase for deeper detection; check MOSFET thermal dissipation. |
| `PI_SETTLING_DELAY_US` | `30` | $\mu\text{s}$ | Wait time after MOSFET turn-OFF to allow back-EMF voltage spike to clamp below 3.3V. | **CRITICAL:** Do NOT sample before 30us to prevent damaging ESP32 ADC pin! |
| `PI_PULSE_PERIOD_US` | `1000` | $\mu\text{s}$ | Repetition period between consecutive pulse bursts (1 kHz rep rate). | Ensures coil magnetic flux collapses completely. |
| `PI_SAMPLE_COUNT` | `16` | Samples | Number of microsecond-spaced ADC decay curve samples per pulse. | Captures decay curve signature. |
| `PI_AVERAGING_COUNT` | `20` | Pulses | Number of consecutive pulse waveforms averaged per measurement frame. | Reduces background electrical noise and ADC jitter. |
| `PI_BASELINE_ALPHA` | `0.05` | Float | Exponential Moving Average (EMA) baseline tracking rate ($0 < \alpha \le 1$). | Slow adaptation rate to track background mineralized seabed baseline. |
| `PI_DEFAULT_THRESHOLD`| `50.0` | ADC Counts | Signal threshold above baseline required to trigger `pi_detected = true`. | Adjust based on benchmark target (ferrous/non-ferrous anomaly spikes). |

> [!WARNING]
> **PROVISIONAL STATUS:** All pulse timings and thresholds are provisional engineering defaults. They MUST be calibrated on an oscilloscope with the physical PI coil and damping resistor.

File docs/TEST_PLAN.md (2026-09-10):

# Comprehensive Test Plan

This document outlines the structured test plan across build, software, bench hardware, water test, and field test phases.

---

## 1. Incremental Verification Stages

```
                  INCREMENTAL FIRMWARE VERIFICATION PIPELINE

[Phase 1: Build] -----> [Phase 2: Simulation] -----> [Phase 3: Bench Hardware]
 Compile & Link           Synthetic Sensor Data         Real Breakout Boards
        |                          |                             |
        v                          v                             v
[BUILD VERIFIED]        [SOFTWARE VERIFIED]           [BENCH HARDWARE VERIFIED]
                                                                 |
                                                                 v
                                                     [Phase 4: Field & Sea Trial]
                                                      Submerged Water & Drift Tests
```

---

## 2. Test Cases

| Test ID | Subsystem | Description | Pass Criteria | Status |
| :--- | :--- | :--- | :--- | :--- |
| **TC-BLD-01** | Build System | Compile full codebase via PlatformIO / ESP32 toolchain. | Zero errors, zero missing header includes. | `[BUILD VERIFIED]` |
| **TC-DRV-01** | MPU6050 Driver | Query `WHO_AM_I` register at I2C address `0x69`. | Returns `0x68` ID byte. | `[BUILD VERIFIED]`, `[SOFTWARE VERIFIED]` |
| **TC-DRV-02** | DS3231 Driver | Query time registers at I2C address `0x68`. | Valid non-zero Unix timestamp returned. | `[BUILD VERIFIED]`, `[SOFTWARE VERIFIED]` |
| **TC-DRV-03** | MAX31865 Driver | Read RTD resistance over SPI Mode 1 (`CS`=5). | Resistance ~ $100\,\Omega - 110\,\Omega$ at room temp. | `[BUILD VERIFIED]`, `[SOFTWARE VERIFIED]` |
| **TC-DRV-04** | RM3100 Driver | Read status and magnetic count registers over SPI Mode 0 (`CS`=4). | Status byte ready, valid magnetic vector $(\mu T)$. | `[BUILD VERIFIED]`, `[SOFTWARE VERIFIED]` |
| **TC-PI-01** | PI Engine | Pulse gate `GPIO33` ($150\,\mu s$), sample ADC `GPIO32` ($30\,\mu s$ delay). | ADC decay curve captured; anomaly strength updated. | `[BUILD VERIFIED]`, `[SOFTWARE VERIFIED]` |
| **TC-FUS-01** | Sensor Fusion | Calculate heading, roll/pitch, and drift bearing. | Valid sector bearing ($0-360^\circ$) & confidence score. | `[BUILD VERIFIED]`, `[SOFTWARE VERIFIED]` |
| **TC-LOG-01** | Logger | Record 100 timestamped sample rows to LittleFS. | File `telemetry.csv` exists and formats properly. | `[BUILD VERIFIED]`, `[SOFTWARE VERIFIED]` |
| **TC-COM-01** | Recovery Wi-Fi | Launch Wi-Fi AP and HTTP server. | `/status` returns JSON telemetry; `/download` streams CSV. | `[BUILD VERIFIED]`, `[SOFTWARE VERIFIED]` |

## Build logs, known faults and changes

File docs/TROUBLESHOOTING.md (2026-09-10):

# Firmware & Hardware Troubleshooting Guide

This document provides diagnostic solutions for common hardware failure modes, bus errors, and sensor operational issues.

---

## 1. Diagnostic Matrix

| Symptom / Fault | Potential Root Cause | Recommended Diagnostic Action |
| :--- | :--- | :--- |
| **MPU6050 missing on I2C scan** | `AD0` pin floating or grounded (`0x68` collision with DS3231). | Verify `AD0` tied to 3.3V (`0x69`). Check SDA/SCL pull-ups. |
| **MAX31865 reading -256.0°C / Fault 0xFF** | SPI CS pin not asserting or RTD disconnected. | Check SPI Mode (must be Mode 1 or 3). Inspect PT100 terminal block connection. |
| **RM3100 reading constant zeros** | `I2CEN` pin not grounded or wrong SPI mode. | Confirm `I2CEN` pin tied to GND. Verify SPI Mode 0 in transaction settings. |
| **PI coil triggers continuous false alarms** | Switching transient delay (`settling_delay_us`) too short. | Increase `settling_delay_us` from 30us to 50us. Re-run `pical` command. |
| **Wi-Fi AP fails to start** | Flash partition table full or brownout reset. | Check 5V power supply capacity. Verify LittleFS partition size. |

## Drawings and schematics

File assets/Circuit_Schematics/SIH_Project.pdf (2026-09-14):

1

2

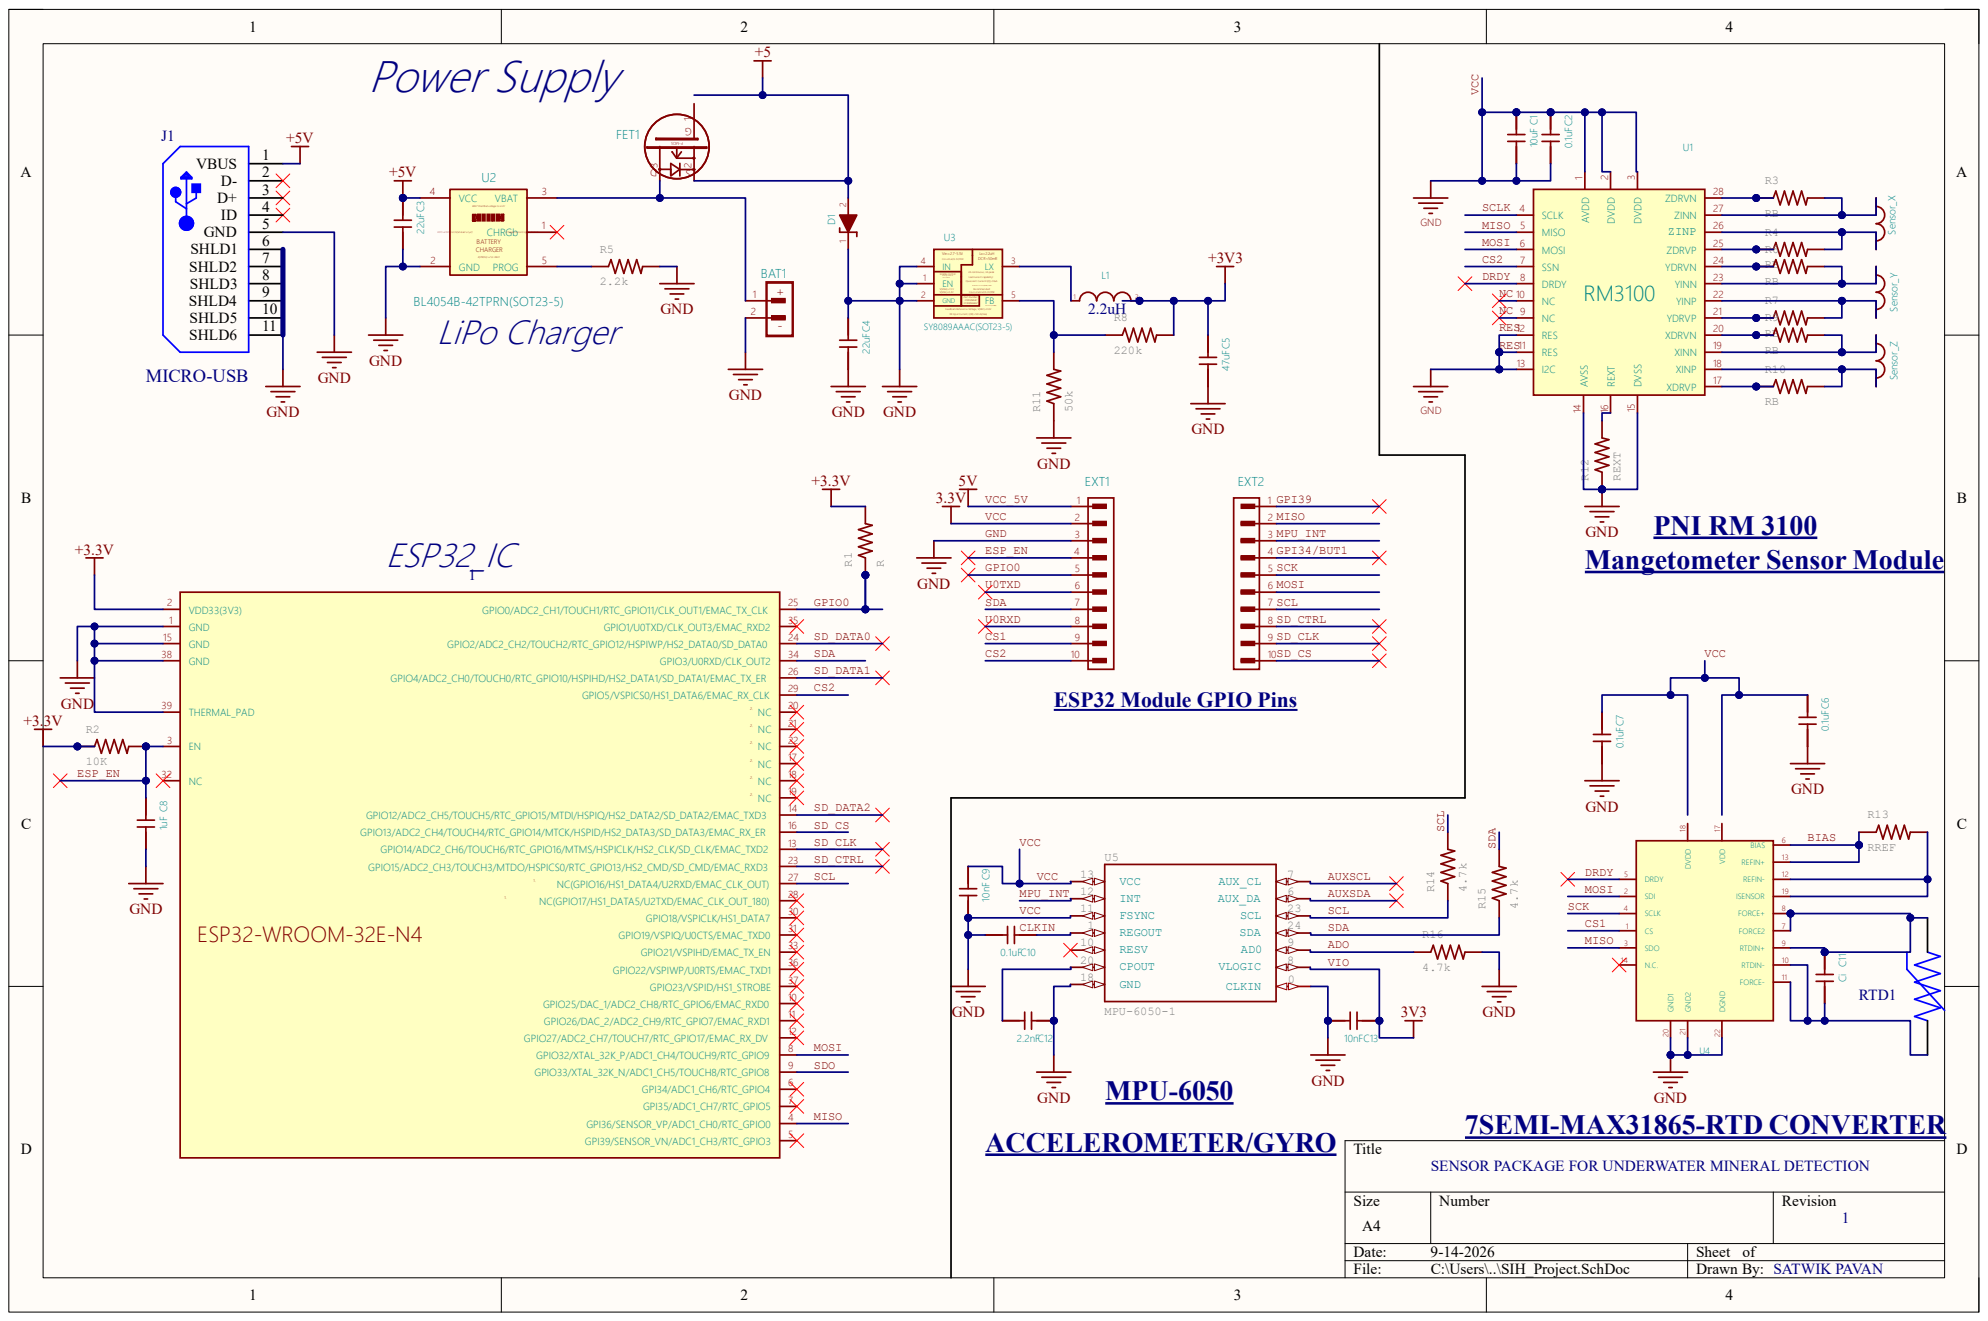
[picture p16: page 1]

VBAT final float voltage to 4.2V

VCC=4.5V to 6.5V(at least a 1 μF)
GND 2
LiPo Charger

Charge Current Up to 800mA

Enable control. Pull high to turn on.

Feedback Reference Voltage, V(REF)=0.6V
FB Input Current, I(FB)=50nA(max)
SY8089AAAC(SOT23-5)

SENSOR PACKAGE FOR UNDERWATER MINERAL DETECTION

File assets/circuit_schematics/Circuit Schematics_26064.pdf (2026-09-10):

1

2

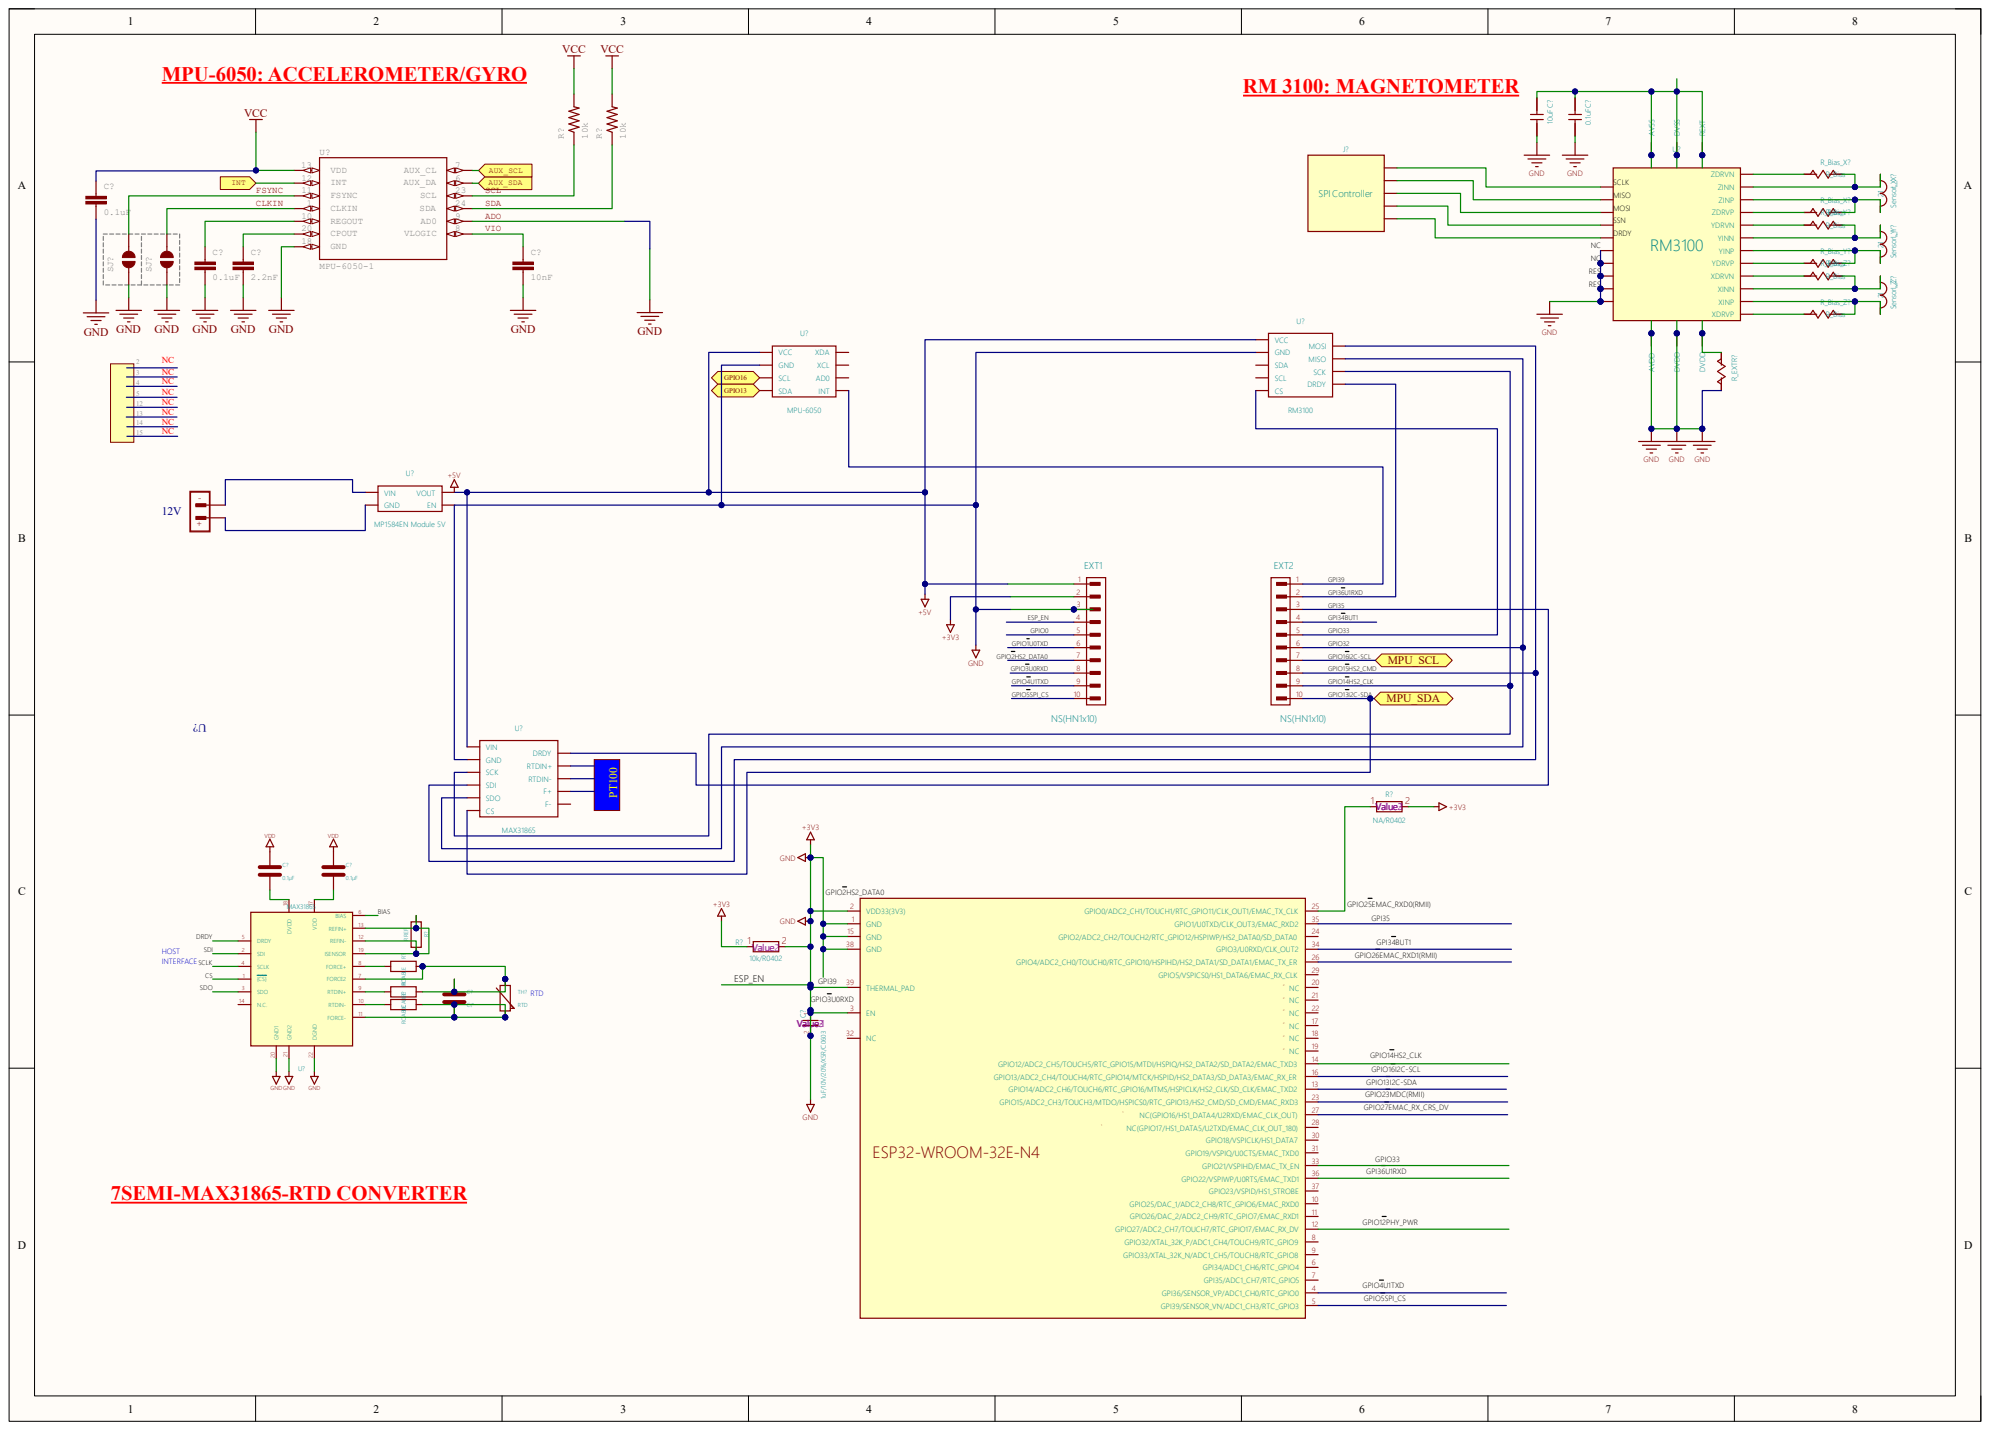
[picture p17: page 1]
VDD 13 INT 12 FSYNC 11 CLKIN 1 REGOUT 10 CPOUT 20 GND 18; AUX_CL; AUX_DA; SCL; SDA; VLOGIC; MPU-6050-1; GND; VCC; GND GND GND; AUX_SDA; AUX_SCL; SCL SDA ADO; INT; FSYNC CLKIN; VIO; EXT1; EXT2; ESP_EN; GPI36U1RXD; GPIO33; GPIO1U0TXD; GPIO4U1TXD; GPIO14HS2_CLK; GPIO32; GPIO0; GPI35; GPIO5SPI_CS; GPIO16I2C-SCL; GPI34BUT1; GPIO3U0RXD; GPI39; GPIO13I2C-SDA; GPIO2HS2_DATA0; GPIO15HS2_CMD; 1 2 Value 1 Value2 10k/R0402; 1 2 Value 1 Value23 NA/R0402; GND¹ ²; Value 1 Value23 1uF/10V/20%/X5R/C⁰⁶⁰³ C?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

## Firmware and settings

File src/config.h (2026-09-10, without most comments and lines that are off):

#define CONFIG_H
#include <Arduino.h>
#include <SPI.h>
#define DEMO_MODE                   0   // 0 = Physical Hardware, 1 = Synthetic Simulation
#define SPI_MISO_PIN                2   // EXT1 Pin 3 (CONFIRMED)
#define RM3100_CS_PIN               4   // EXT1 Pin 4 (CONFIRMED, Active LOW)
#define MAX31865_CS_PIN             5   // EXT1 Pin 5 (CONFIRMED, Active LOW)
#define I2C_SDA_PIN                 13  // EXT2 Pin 3 (CONFIRMED)
#define SPI_SCK_PIN                 14  // EXT2 Pin 7 (CONFIRMED)
#define SPI_MOSI_PIN                15  // EXT2 Pin 8 (CONFIRMED)
#define PI_ADC_INPUT_PIN            32  // EXT2 Pin 6 (CONFIRMED, ADC1_CH4)
#define PI_MOSFET_GATE_PIN          33  // EXT2 Pin 5 (CONFIRMED, Digital Output)
#define I2C_SCL_PIN                 16  // HARDWARE_TBD (Prompt specifies GPIO?, default 16 for Olimex EXT2)
#define RM3100_DRDY_PIN             -1  // HARDWARE_TBD (Unassigned on ESP32, polling mode used)
#define I2C_BUS_SPEED               400000U // 400 kHz Fast-Mode I2C
#define RM3100_SPI_FREQ             1000000U
#define RM3100_SPI_MODE             SPI_MODE0
#define MAX31865_SPI_FREQ           1000000U
#define MAX31865_SPI_MODE           SPI_MODE1
#define MPU6050_I2C_ADDR_DEFAULT    0x69 // Configurable (Default 0x69, AD0 tied to 3.3V)
#define BODY_AXIS_X_SIGN            ( 1.0f)
#define BODY_AXIS_Y_SIGN            ( 1.0f)
#define BODY_AXIS_Z_SIGN            ( 1.0f)
#define MAX31865_RREF_OHMS          430.0f // Subject to bench measurement of 7Semi board
#define MAX31865_RNOMINAL_OHMS      100.0f // PT100 0°C nominal resistance
#define ATTITUDE_ALPHA              0.98f  // Complementary filter weight
#define IMU_MOTION_THRESHOLD_M_S2   0.15f  // Min horizontal acceleration to consider IMU direction valid
#define FUSION_WEIGHT_MAG           0.80f
#define FUSION_WEIGHT_IMU           0.20f
#define DEFAULT_DRIFT_RADIUS_M      400.0f // Renamed from uncertainty radius to deployment drift radius
#define DEFAULT_UNCERTAINTY_DEG     30.0f  // Half-angle uncertainty sector (total cone = 60 deg)
#define PI_PULSE_WIDTH_US           150   // Pulse duration MOSFET Gate ON
#define PI_SETTLING_DELAY_US        30    // Flyback clamp settling delay
#define PI_PULSE_PERIOD_US         1000   // Repetition period between pulses
#define PI_SAMPLE_COUNT              16   // Number of microsecond samples per decay curve
#define PI_AVERAGING_COUNT           20   // Number of pulses averaged per burst
#define PI_BASELINE_ALPHA          0.05f  // Baseline EMA tracking rate
#define PI_DEFAULT_THRESHOLD       50.0f  // Default anomaly detection threshold (ADC counts)
#define PI_THRESHOLD_SIGMA_MULT     3.5f  // Multiplier for noise-derived threshold during calibration
struct MagCalibrationData {
    float offset_x;
    float offset_y;
    float offset_z;
    float scale_x;
    float scale_y;
    float scale_z;
    bool is_calibrated;
};
struct ImuCalibrationData {
    float accel_offset_x;
    float accel_offset_y;
    float accel_offset_z;
    float gyro_offset_x;
    float gyro_offset_y;
    float gyro_offset_z;
    bool is_calibrated;
};
struct PiCalibrationData {
    float baseline_counts;
    float noise_sigma;
    float derived_threshold;
    bool is_calibrated;
};
struct SensorSample {
    uint32_t timestamp_epoch;            // DS3231 Unix timestamp (seconds)
    uint32_t timestamp_us;               // High-resolution boot microseconds
    char iso_timestamp[32];              // Formatted ISO-8601 UTC string
    bool mpu_valid;                      // True if MPU6050 returned valid data
    bool mag_valid;                      // True if RM3100 returned valid data
    bool rtd_valid;                      // True if MAX31865 reading valid & no fault
    bool rtc_valid;                      // True if DS3231 communication & time valid
    bool pi_valid;                       // True if PI acquisition succeeded
    bool imu_direction_valid;            // True if horizontal acceleration exceeds threshold
    int16_t raw_accel_x, raw_accel_y, raw_accel_z; // Raw MPU6050 LSBs
    int16_t raw_gyro_x, raw_gyro_y, raw_gyro_z;    // Raw Gyro LSBs
    int16_t raw_mpu_temp;                          // Raw MPU6050 die temp LSBs
    int32_t raw_mag_x, raw_mag_y, raw_mag_z;       // Raw RM3100 counts (24-bit)
    uint16_t raw_rtd_count;                        // Raw MAX31865 15-bit RTD count
    uint8_t rtd_fault_byte;                        // MAX31865 fault register
    uint16_t pi_raw_decay[PI_SAMPLE_COUNT];        // Raw PI microsecond decay waveform
    float water_temperature_C;           // Seawater temperature via MAX31865 PT100 probe
    float rtd_resistance_ohms;           // Measured PT100 resistance
    float imu_die_temperature_C;         // Internal MPU6050 die temperature
    float accel_x_m_s2;                  // Calibrated acceleration X
    float accel_y_m_s2;                  // Calibrated acceleration Y
    float accel_z_m_s2;                  // Calibrated acceleration Z
    float gyro_x_rad_s;                  // Calibrated gyroscope X
    float gyro_y_rad_s;                  // Calibrated gyroscope Y
    float gyro_z_rad_s;                  // Calibrated gyroscope Z
    float roll_deg;                      // Estimated roll angle
    float pitch_deg;                     // Estimated pitch angle
    float mag_x_uT;                      // Calibrated magnetic field X
    float mag_y_uT;                      // Calibrated magnetic field Y
    float mag_z_uT;                      // Calibrated magnetic field Z
    float magnetic_heading_deg;          // Tilt-compensated heading (0-360 deg)
    float pi_baseline;                   // Background zero-metal decay baseline
    float pi_peak;                       // Peak amplitude of decay waveform
    float pi_early_decay;                // Mean of early decay samples (fast transient)
    float pi_late_decay;                 // Mean of late decay samples (eddy current decay)
    float pi_anomaly_strength;           // Anomaly magnitude above baseline
    bool pi_detected;                    // True if anomaly strength exceeds threshold
    float accel_horiz_mag;               // Gravity-compensated horizontal acceleration
    float imu_drift_heading_deg;         // Direction derived from short-term IMU motion
    float estimated_drift_bearing_deg;   // Fused dominant drift bearing
    float uncertainty_angle_deg;         // Sector half-angle (e.g. +/-30 deg)
    float deployment_drift_radius_m;     // Operational drift radius (400 m)
    float magnetic_confidence;           // Magnetic reading confidence (0.0 to 1.0)
    float imu_confidence;                // IMU motion signal confidence (0.0 to 1.0)
    float fusion_confidence;             // Combined fusion confidence score (0.0 to 1.0)
};

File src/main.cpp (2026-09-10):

#include <Arduino.h>
#include <Wire.h>
#include <SPI.h>

#include "config.h"
#include "sensors/mpu6050.h"
#include "sensors/max31865_pt100.h"
#include "sensors/rm3100.h"
#include "pi/pi_detector.h"
#include "fusion/attitude.h"
#include "fusion/heading.h"
#include "fusion/drift_fusion.h"
#include "logging/logger.h"
#include "communication/wifi_manager.h"
#include "diagnostics/diagnostics.h"

// Global Hardware Instances
MPU6050Sensor       g_mpu(MPU6050_I2C_ADDR_DEFAULT);
DS3231RTC           g_rtc;
MAX31865Sensor      g_rtd(MAX31865_CS_PIN);
RM3100Sensor        g_mag(RM3100_CS_PIN);
PIDetector          g_pi(PI_MOSFET_GATE_PIN, PI_ADC_INPUT_PIN);

// Global Processing & Communication Instances
AttitudeFilter      g_attitude;
HeadingCalculator   g_heading;
DriftFusionEngine   g_driftFusion;
TelemetryLogger     g_logger;
WiFiRecoveryManager g_wifi;

// Global Shared Data Record
SensorSample        g_latestSample;

// Runtime Flags
static bool g_demoModeActive = (DEMO_MODE == 1);
static uint32_t lastLoopTimeMs = 0;
static uint32_t lastSampleTimeMs = 0;
static uint32_t simStepCount = 0;

// Forward Declarations
void processSerialCLI();
void executeMagCal();
void executeImuCal();
void executePiRead();
void executePiCal();
void runSimulationStep(float dt_s);

void setup() {
    Serial.begin(115200);
    delay(1000);
    Serial.println("\n=======================================================");
    Serial.println("  MoES Seafloor Metal Detection Sensor Package Firmware");
    Serial.println("  Problem Statement ID: 26064 (MoES / NCPOR)");
    Serial.println("  PROTOTYPE SCOPE: Bench Bring-Up / Field Drift Estimator");
    Serial.println("=======================================================");

    // 1. Initialize I2C Bus
    Wire.begin(I2C_SDA_PIN, I2C_SCL_PIN, I2C_BUS_SPEED);
    Serial.printf("[SYSTEM] I2C Bus Initialized (SDA=GPIO%u, SCL=GPIO%u [HARDWARE_TBD], Speed=%u Hz)\n",
                  I2C_SDA_PIN, I2C_SCL_PIN, I2C_BUS_SPEED);

    // 2. Initialize Shared SPI Bus
    SPI.begin(SPI_SCK_PIN, SPI_MISO_PIN, SPI_MOSI_PIN);
    Serial.printf("[SYSTEM] Shared SPI Bus Initialized (SCK=GPIO%u, MISO=GPIO%u, MOSI=GPIO%u)\n",
                  SPI_SCK_PIN, SPI_MISO_PIN, SPI_MOSI_PIN);

    // 3. Bring Up Peripherals with Strict Order & Startup Identity Checks
    // DS3231 RTC checked first at fixed address 0x68
    g_rtc.begin(Wire, DS3231_I2C_ADDR);

    // MPU6050 strictly checked at configured address 0x69 (no fallback to 0x68)
    g_mpu.begin(Wire, MPU6050_I2C_ADDR_DEFAULT);

    // MAX31865 RTD converter on SPI CS GPIO5 (SPI Mode 1)
    g_rtd.begin(SPI, MAX31865_RREF_OHMS, MAX31865_RNOMINAL_OHMS);

    // RM3100 Magnetometer on SPI CS GPIO4 (SPI Mode 0)
    g_mag.begin(SPI);

    // Parameterized Pulse Induction Engine (Gate GPIO33, ADC GPIO32)
    g_pi.begin();

    // 4. Initialize Data Storage & Recovery Server
    g_logger.begin();
    g_wifi.begin("MoES_Sensor_Recovery", "Seafloor2026");

    // 5. Print Boot Hardware Status Table
    SystemDiagnostics::printSelfTestTable(g_mpu, g_rtc, g_rtd, g_mag, g_pi, g_logger, g_wifi);

    if (g_demoModeActive) {
        Serial.println("[SYSTEM] DEMO_MODE is ENABLED. Generating synthetic telemetry.");
    }

    Serial.println("System Ready. Type 'help' for interactive CLI commands.");
    lastLoopTimeMs = millis();
}

void loop() {
    uint32_t nowMs = millis();
    float dt_s = (nowMs - lastLoopTimeMs) / 1000.0f;
    if (dt_s <= 0.0f) dt_s = 0.01f;
    lastLoopTimeMs = nowMs;

    // Handle background Wi-Fi HTTP Server requests
    g_wifi.handleClient();

    // Handle Serial Console CLI input
    if (Serial.available()) {
        processSerialCLI();
    }

    // Time-Multiplexed Sensor Acquisition Loop (100 ms = 10 Hz rate)
    if (nowMs - lastSampleTimeMs >= 100) {
        lastSampleTimeMs = nowMs;

        if (g_demoModeActive) {
            runSimulationStep(dt_s);
        } else {
            // --- STEP A: RTC TIME ---
            g_latestSample.rtc_valid = g_rtc.readTime(g_latestSample.timestamp_epoch,
                                                      g_latestSample.iso_timestamp,
                                                      sizeof(g_latestSample.iso_timestamp));
            g_latestSample.timestamp_us = micros();

            // --- STEP B: SEAWATER RTD TEMPERATURE ---
            g_latestSample.rtd_valid = g_rtd.readScaled(g_latestSample.water_temperature_C,
                                                        g_latestSample.rtd_resistance_ohms,
                                                        g_latestSample.rtd_fault_byte);

            // --- STEP C: MPU6050 MOTION & DIE TEMPERATURE ---
            g_latestSample.mpu_valid = g_mpu.readScaled(g_latestSample.accel_x_m_s2,
                                                        g_latestSample.accel_y_m_s2,
                                                        g_latestSample.accel_z_m_s2,
                                                        g_latestSample.gyro_x_rad_s,
                                                        g_latestSample.gyro_y_rad_s,
                                                        g_latestSample.gyro_z_rad_s,
                                                        g_latestSample.imu_die_temperature_C);
            if (g_latestSample.mpu_valid) {
                g_attitude.update(g_latestSample.accel_x_m_s2,
                                  g_latestSample.accel_y_m_s2,
                                  g_latestSample.accel_z_m_s2,
                                  g_latestSample.gyro_x_rad_s,
                                  g_latestSample.gyro_y_rad_s,
                                  g_latestSample.gyro_z_rad_s,
                                  dt_s,
                                  g_latestSample.roll_deg,
                                  g_latestSample.pitch_deg);
            }

            // --- STEP D: RM3100 MAGNETOMETER (Time Window: PI OFF) ---
            g_latestSample.mag_valid = g_mag.readScaled(g_latestSample.mag_x_uT,
                                                        g_latestSample.mag_y_uT,
                                                        g_latestSample.mag_z_uT);
            if (g_latestSample.mag_valid) {
                g_latestSample.magnetic_heading_deg = g_heading.calculateHeading(
                    g_latestSample.mag_x_uT, g_latestSample.mag_y_uT, g_latestSample.mag_z_uT,
                    g_latestSample.roll_deg, g_latestSample.pitch_deg);
            }

            // --- STEP E: PULSE INDUCTION (Time Window: Mag read complete) ---
            g_latestSample.pi_valid = g_pi.processPulseSequence(
                g_latestSample.pi_raw_decay,
                g_latestSample.pi_baseline,
                g_latestSample.pi_peak,
                g_latestSample.pi_early_decay,
                g_latestSample.pi_late_decay,
                g_latestSample.pi_anomaly_strength,
                g_latestSample.pi_detected);

            // --- STEP F: SENSOR FUSION & CONDITIONAL DRIFT SECTOR ---
            float magMag = sqrtf(g_latestSample.mag_x_uT * g_latestSample.mag_x_uT +
                                 g_latestSample.mag_y_uT * g_latestSample.mag_y_uT +
                                 g_latestSample.mag_z_uT * g_latestSample.mag_z_uT);

            g_driftFusion.computeDriftSector(
                g_latestSample.magnetic_heading_deg, magMag,
                g_latestSample.accel_x_m_s2, g_latestSample.accel_y_m_s2, g_latestSample.accel_z_m_s2,
                g_latestSample.roll_deg, g_latestSample.pitch_deg,
                g_latestSample.mag_valid, g_latestSample.mpu_valid,
                g_latestSample.accel_horiz_mag,
                g_latestSample.imu_drift_heading_deg,
                g_latestSample.imu_direction_valid,
                g_latestSample.estimated_drift_bearing_deg,
                g_latestSample.uncertainty_angle_deg,
                g_latestSample.deployment_drift_radius_m,
                g_latestSample.magnetic_confidence,
                g_latestSample.imu_confidence,
                g_latestSample.fusion_confidence);
        }

        // --- STEP G: LOG TELEMETRY SAMPLE ---
        g_logger.logSample(g_latestSample);
    }
}

void runSimulationStep(float dt_s) {
    simStepCount++;
    float t = simStepCount * 0.1f; // Simulation time in seconds

    // 1. Timestamps
    g_latestSample.timestamp_epoch = 1788780000 + (uint32_t)t;
    g_latestSample.timestamp_us = micros();
    snprintf(g_latestSample.iso_timestamp, sizeof(g_latestSample.iso_timestamp),
             "2026-09-07T14:30:%02u.%03uZ", (uint32_t)t % 60, (uint32_t)(t * 1000) % 1000);

    // 2. Validity Flags
    g_latestSample.mpu_valid = true;
    g_latestSample.mag_valid = true;
    g_latestSample.rtd_valid = true;
    g_latestSample.rtc_valid = true;
    g_latestSample.pi_valid  = true;

    // 3. Simulated Seawater & Die Temperatures
    g_latestSample.water_temperature_C = 4.2f + 0.1f * sinf(t * 0.05f); // Deep sea ~4°C
    g_latestSample.rtd_resistance_ohms = 101.64f;
    g_latestSample.rtd_fault_byte = 0;
    g_latestSample.imu_die_temperature_C = 28.5f + 0.2f * sinf(t * 0.02f);

    // 4. Simulated Vessel Motion & Attitude (Gentle oscillating roll & pitch)
    g_latestSample.roll_deg = 3.5f * sinf(t * 0.8f);
    g_latestSample.pitch_deg = 2.0f * cosf(t * 0.6f);

    // Simulated horizontal transient acceleration (bursts every 10 seconds)
    float horizAccel = 0.05f;
    if (fmodf(t, 10.0f) < 2.5f) {
        horizAccel = 0.35f; // Active motion burst
    }
    g_latestSample.accel_x_m_s2 = horizAccel * cosf(t * 0.1f);
    g_latestSample.accel_y_m_s2 = horizAccel * sinf(t * 0.1f);
    g_latestSample.accel_z_m_s2 = 9.81f;
    g_latestSample.gyro_x_rad_s = 0.02f * cosf(t * 0.8f);
    g_latestSample.gyro_y_rad_s = -0.01f * sinf(t * 0.6f);
    g_latestSample.gyro_z_rad_s = 0.005f;

    // 5. Simulated Magnetic Field (Dominant North-East Drift at ~45 degrees + small fin oscillation)
    float baseHeading = 45.0f + 5.0f * sinf(t * 0.2f);
    g_latestSample.magnetic_heading_deg = baseHeading;
    g_latestSample.mag_x_uT = 30.0f * cosf(baseHeading * (3.14159f / 180.0f));
    g_latestSample.mag_y_uT = 30.0f * sinf(baseHeading * (3.14159f / 180.0f));
    g_latestSample.mag_z_uT = 38.0f;

    // 6. Simulated PI Decay & Periodic Metal Anomaly Injection
    g_latestSample.pi_baseline = 120.0f;
    bool injectMetal = (fmodf(t, 15.0f) < 3.0f); // Metal anomaly every 15s
    float anomalyMag = injectMetal ? 180.0f : 5.0f;

    g_latestSample.pi_peak = g_latestSample.pi_baseline + anomalyMag;
    g_latestSample.pi_early_decay = g_latestSample.pi_baseline + (anomalyMag * 0.7f);
    g_latestSample.pi_late_decay  = g_latestSample.pi_baseline + (anomalyMag * 0.2f);
    g_latestSample.pi_anomaly_strength = anomalyMag;
    g_latestSample.pi_detected = (anomalyMag >= PI_DEFAULT_THRESHOLD);

    for (int i = 0; i < PI_SAMPLE_COUNT; i++) {
        g_latestSample.pi_raw_decay[i] = (uint16_t)(g_latestSample.pi_peak * expf(-i * 0.2f));
    }

    // 7. Sensor Fusion
    float magMag = sqrtf(g_latestSample.mag_x_uT * g_latestSample.mag_x_uT +
                         g_latestSample.mag_y_uT * g_latestSample.mag_y_uT +
                         g_latestSample.mag_z_uT * g_latestSample.mag_z_uT);

    g_driftFusion.computeDriftSector(
        g_latestSample.magnetic_heading_deg, magMag,
        g_latestSample.accel_x_m_s2, g_latestSample.accel_y_m_s2, g_latestSample.accel_z_m_s2,
        g_latestSample.roll_deg, g_latestSample.pitch_deg,
        g_latestSample.mag_valid, g_latestSample.mpu_valid,
        g_latestSample.accel_horiz_mag,
        g_latestSample.imu_drift_heading_deg,
        g_latestSample.imu_direction_valid,
        g_latestSample.estimated_drift_bearing_deg,
        g_latestSample.uncertainty_angle_deg,
        g_latestSample.deployment_drift_radius_m,
        g_latestSample.magnetic_confidence,
        g_latestSample.imu_confidence,
        g_latestSample.fusion_confidence);
}

void executePiRead() {
    Serial.println("\n[PI_READ] Triggering live Pulse Induction diagnostic read...");
    uint16_t decayCurve[PI_SAMPLE_COUNT] = {0};
    uint16_t avg = g_pi.sampleSinglePulse(decayCurve, PI_SAMPLE_COUNT);

    Serial.printf("  Decay Waveform Samples (16 microsecond points): [");
    for (int i = 0; i < PI_SAMPLE_COUNT; i++) {
        Serial.printf("%u%s", decayCurve[i], (i < PI_SAMPLE_COUNT - 1) ? ", " : "");
    }
    Serial.println("]");

    float baseline, peak, early, late, strength;
    bool detected;
    g_pi.processPulseSequence(decayCurve, baseline, peak, early, late, strength, detected);

    Serial.printf("  Burst Metrics: Peak=%.1f | Early=%.1f | Late=%.1f | Baseline=%.1f | Anomaly Strength=%.1f\n",
                  peak, early, late, baseline, strength);
    Serial.printf("  Metal Anomaly Status: %s\n\n", detected ? ">>> METAL DETECTED <<<" : "CLEAR (NO TARGET)");
}

void executePiCal() {
    Serial.println("\n=======================================================");
    Serial.println("     PULSE INDUCTION NO-TARGET BASELINE CALIBRATION");
    Serial.println("=======================================================");
    Serial.println("Ensure coil is away from all metallic objects.");
    Serial.println("Collecting 20 baseline pulse sequences to estimate noise floor...\n");

    PiCalibrationData cal;
    if (g_pi.calibrateNoTarget(20, cal)) {
        Serial.printf("  Measured Baseline : %.1f ADC counts\n", cal.baseline_counts);
        Serial.printf("  Noise Sigma (RMS) : %.2f ADC counts\n", cal.noise_sigma);
        Serial.printf("  Derived Threshold : %.1f ADC counts (%.1f x sigma)\n", cal.derived_threshold, PI_THRESHOLD_SIGMA_MULT);
        Serial.println("[PI_CAL] Calibration stored and active.\n");
    } else {
        Serial.println("[PI_CAL] ERROR: Calibration failed.\n");
    }
}

void executeMagCal() {
    Serial.println("\n=======================================================");
    Serial.println("         RM3100 3D MAGNETOMETER CALIBRATION");
    Serial.println("=======================================================");
    Serial.println("Rotate sensor package slowly through all 3D orientations.");
    Serial.println("Collecting samples for 15 seconds...\n");

    float minX = 9999.0f, maxX = -9999.0f;
    float minY = 9999.0f, maxY = -9999.0f;
    float minZ = 9999.0f, maxZ = -9999.0f;

    uint32_t startMs = millis();
    uint32_t sampleCount = 0;

    while (millis() - startMs < 15000) {
        float mx, my, mz;
        if (g_mag.readScaled(mx, my, mz)) {
            if (mx < minX) minX = mx;
            if (mx > maxX) maxX = mx;
            if (my < minY) minY = my;
            if (my > maxY) maxY = my;
            if (mz < minZ) minZ = mz;
            if (mz > maxZ) maxZ = mz;
            sampleCount++;
        }
        if (sampleCount % 10 == 0) {
            Serial.printf("  Samples: %u | X:[%.1f, %.1f] Y:[%.1f, %.1f] Z:[%.1f, %.1f]\r",
                          sampleCount, minX, maxX, minY, maxY, minZ, maxZ);
        }
        delay(50);
    }

    Serial.println("\n\nCalculating Hard-Iron & Soft-Iron Offsets...");
    MagCalibrationData cal;
    cal.offset_x = (maxX + minX) / 2.0f;
    cal.offset_y = (maxY + minY) / 2.0f;
    cal.offset_z = (maxZ + minZ) / 2.0f;

    float deltaX = (maxX - minX) / 2.0f;
    float deltaY = (maxY - minY) / 2.0f;
    float deltaZ = (maxZ - minZ) / 2.0f;
    float avgDelta = (deltaX + deltaY + deltaZ) / 3.0f;

    cal.scale_x = (deltaX > 0.1f) ? (avgDelta / deltaX) : 1.0f;
    cal.scale_y = (deltaY > 0.1f) ? (avgDelta / deltaY) : 1.0f;
    cal.scale_z = (deltaZ > 0.1f) ? (avgDelta / deltaZ) : 1.0f;
    cal.is_calibrated = true;

    g_heading.setCalibration(cal);

    Serial.printf("  Offset (uT) : X=%.2f, Y=%.2f, Z=%.2f\n", cal.offset_x, cal.offset_y, cal.offset_z);
    Serial.printf("  Scale Multi : X=%.3f, Y=%.3f, Z=%.3f\n", cal.scale_x, cal.scale_y, cal.scale_z);
    Serial.println("[MAG_CAL] Calibration applied to active Heading Calculator.\n");
}

void executeImuCal() {
    Serial.println("\n=======================================================");
    Serial.println("           MPU6050 ZERO-MOTION IMU CALIBRATION");
    Serial.println("=======================================================");
    Serial.println("Keep sensor COMPLETELY STILL on a level surface.");
    Serial.println("Collecting 200 samples over 4 seconds...\n");

    float sumAx = 0, sumAy = 0, sumAz = 0;
    float sumGx = 0, sumGy = 0, sumGz = 0;
    const uint16_t numSamples = 200;

    for (uint16_t i = 0; i < numSamples; i++) {
        float ax, ay, az, gx, gy, gz, t;
        g_mpu.readScaled(ax, ay, az, gx, gy, gz, t);
        sumAx += ax; sumAy += ay; sumAz += az;
        sumGx += gx; sumGy += gy; sumGz += gz;
        delay(20);
    }

    ImuCalibrationData cal;
    cal.accel_offset_x = sumAx / numSamples;
    cal.accel_offset_y = sumAy / numSamples;
    cal.accel_offset_z = (sumAz / numSamples) - 9.80665f; // Zero out 1g gravity on Z
    cal.gyro_offset_x  = sumGx / numSamples;
    cal.gyro_offset_y  = sumGy / numSamples;
    cal.gyro_offset_z  = sumGz / numSamples;
    cal.is_calibrated  = true;

    g_mpu.setCalibration(cal);

    Serial.printf("  Accel Offsets (m/s^2): X=%.3f, Y=%.3f, Z=%.3f\n", cal.accel_offset_x, cal.accel_offset_y, cal.accel_offset_z);
    Serial.printf("  Gyro Offsets (rad/s) : X=%.4f, Y=%.4f, Z=%.4f\n", cal.gyro_offset_x, cal.gyro_offset_y, cal.gyro_offset_z);
    Serial.println("[IMU_CAL] Calibration applied to active MPU6050 instance.\n");
}

void processSerialCLI() {
    String cmd = Serial.readStringUntil('\n');
    cmd.trim();
    if (cmd.length() == 0) return;

    if (cmd == "help") {
        Serial.println("\n--- MoES CLI Command Help ---");
        Serial.println("  status       : Print system diagnostic hardware table");
        Serial.println("  i2cscan      : Perform I2C bus scanner probe");
        Serial.println("  readimu      : Read MPU6050 accelerometer, gyro & die temp");
        Serial.println("  readmag      : Read RM3100 magnetic vector & heading");
        Serial.println("  readtemp     : Read MAX31865 seawater RTD temperature");
        Serial.println("  readrtc      : Read DS3231 timestamp");
        Serial.println("  piread       : Fire live PI pulse burst & display decay curve");
        Serial.println("  pical        : Run no-target noise-sigma PI calibration");
        Serial.println("  magcal       : Run 15-second interactive 3D magnetometer calibration");
        Serial.println("  imucal       : Run zero-motion IMU bias calibration");
        Serial.println("  demo         : Toggle DEMO_MODE synthetic simulation");
        Serial.println("  wifi         : Display Wi-Fi Access Point IP & endpoint status");
        Serial.println("  reboot       : Soft restart ESP32 MCU\n");
    } else if (cmd == "status") {
        SystemDiagnostics::printSelfTestTable(g_mpu, g_rtc, g_rtd, g_mag, g_pi, g_logger, g_wifi);
    } else if (cmd == "i2cscan") {
        SystemDiagnostics::scanI2CBus(Wire);
    } else if (cmd == "readimu") {
        Serial.printf("IMU: Valid=%d | Accel=(%.2f, %.2f, %.2f) m/s^2 | Gyro=(%.3f, %.3f, %.3f) rad/s | Die Temp=%.1f°C | Roll=%.1f° Pitch=%.1f°\n",
                      g_latestSample.mpu_valid,
                      g_latestSample.accel_x_m_s2, g_latestSample.accel_y_m_s2, g_latestSample.accel_z_m_s2,
                      g_latestSample.gyro_x_rad_s, g_latestSample.gyro_y_rad_s, g_latestSample.gyro_z_rad_s,
                      g_latestSample.imu_die_temperature_C,
                      g_latestSample.roll_deg, g_latestSample.pitch_deg);
    } else if (cmd == "readmag") {
        Serial.printf("MAG: Valid=%d | Vector=(%.2f, %.2f, %.2f) uT | Heading=%.1f° | Mag Conf=%.2f\n",
                      g_latestSample.mag_valid,
                      g_latestSample.mag_x_uT, g_latestSample.mag_y_uT, g_latestSample.mag_z_uT,
                      g_latestSample.magnetic_heading_deg, g_latestSample.magnetic_confidence);
    } else if (cmd == "readtemp") {
        Serial.printf("RTD: Valid=%d | Water Temp=%.2f °C | Resistance=%.2f ohms | Fault=0x%02X\n",
                      g_latestSample.rtd_valid,
                      g_latestSample.water_temperature_C, g_latestSample.rtd_resistance_ohms, g_latestSample.rtd_fault_byte);
    } else if (cmd == "readrtc") {
        Serial.printf("RTC: Valid=%d | Epoch=%u | ISO String=%s\n",
                      g_latestSample.rtc_valid,
                      g_latestSample.timestamp_epoch, g_latestSample.iso_timestamp);
    } else if (cmd == "piread") {
        executePiRead();
    } else if (cmd == "pical") {
        executePiCal();
    } else if (cmd == "magcal") {
        executeMagCal();
    } else if (cmd == "imucal") {
        executeImuCal();
    } else if (cmd == "demo") {
        g_demoModeActive = !g_demoModeActive;
        Serial.printf("DEMO_MODE is now %s\n", g_demoModeActive ? "ENABLED (Simulation Active)" : "DISABLED (Hardware Active)");
    } else if (cmd == "wifi") {
        g_wifi.printDiagnostics();
    } else if (cmd == "reboot") {
        Serial.println("Rebooting ESP32...");
        ESP.restart();
    } else {
        Serial.printf("Unknown command '%s'. Type 'help' for command list.\n", cmd.c_str());
    }
}

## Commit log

2026-09-10 Initial commit: Seafloor-Metal-Detection-EmbedX
    [Circuit Schematics_26064.SchDoc, Payload Schematics_26064.scad, Payload carrier and lander schematics_26064.scad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]
2026-09-10 Screenshots demonstrating the current software prototype
2026-09-14 Create Circuit_Schematics
